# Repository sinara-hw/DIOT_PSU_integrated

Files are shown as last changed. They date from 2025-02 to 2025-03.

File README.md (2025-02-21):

# DIOT_PSU_integrated
DIOT_PSU_integrated  - Power supply module for DIOT system.

## Design Files

Design files (schematics, PCB layouts, BOMs) can be found at [DIOT_PSU_integrated/Releases](https://github.com/sinara-hw/DIOT_PSU_integrated).

## Wiki

More information can be found on the [wiki](https://github.com/sinara-hw/DIOT_PSU_integrated/wiki).

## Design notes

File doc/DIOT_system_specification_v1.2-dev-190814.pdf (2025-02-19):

# Distributed I/O Tier system specification

## v1.2-dev-190813

### Greg Daniluk (BE-CO) <grzegorz.daniluk@cern.ch>

### Evangelia Gousiou, Lalit Patnaik, Christos Gentsos, Ioan Kozsar (BE-CO)

### Mateusz Sosin, Kamil Kucel, Paul Peronnard (EN-SMM)

### Pieter Van Trappen (TE-ABT)

### Alain Antoine, Richard Mompo (TE-MPE)

### Grzegorz Kasprowicz (Creotech Instruments)

## Table of Contents

## Revision table

Date | Version | Comments
2018-12-20 | First draft | First draft released for comments
2019-02-28 | 2 nd draft | Including input from Creotech
2019-03-29 | rd draft 3 | Including monitoring-related backplane connectors
2019-04-11 | 4 th draft | Including input from CERN Eq groups
2019-05-06 | 1.0 release | Ready for crate mechanics & backplane design

## 1 Introduction

Controls and data acquisition systems in accelerators often involve a computing platform (VME, PICMG 1.3, MTCA.4...) connected to Distributed I/O Tier electronics using a fieldbus communication link (Figure 1). The devices in the Distributed I/O Tier communicate directly with various sensors and actuators and are deployed close to the machine. Since these areas are frequently exposed to radiation and because of the very specific needs of CERN systems, these modules not being commercially available, are usually custom in-house developments. Currently, we are missing a centrally supported service at CERN for the custom electronics in this layer.

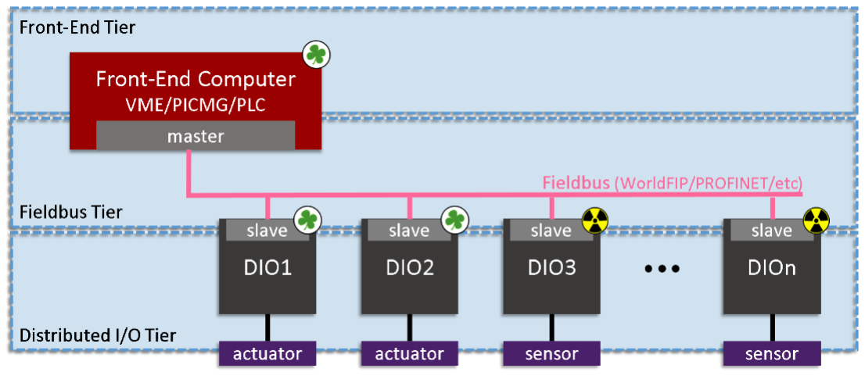
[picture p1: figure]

Figure 1: Three lowest hardware layers of a typical control system

The Distributed I/O Tier project aims at offering a new, modular and reusable hardware kit for various renovations and new systems to be deployed for the High Luminosity LHC (HL-LHC) in 2025. The kit to cover the requirements of the equipment groups in both radiation-exposed and radiation-free areas will consist of the following components (Figure 2):

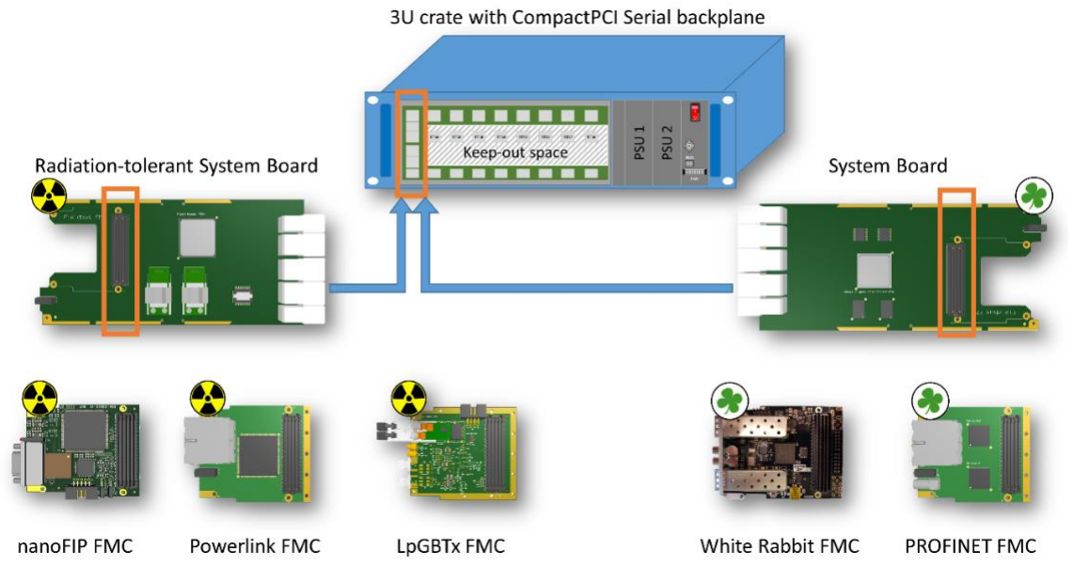
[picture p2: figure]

Figure 2: Distributed I/O Tier modular and reusable hardware kit

- A low-cost CompactPCI Serial chassis with a backplane and redundant power supplies (either off-the-shelf or radiation-tolerant in-house designed).
- Two generic FPGA-based System Boards (radiation-tolerant and non-radiation-tolerant) that interface with the application-specific peripheral boards plugged into the other slots of the 3U crate. Each System Board features a high-performance FPGA for the application-specific logic. A small fraction of the FPGA resources is dedicated to standardised crate diagnostics. The System Boards have an LPC FMC slot, where a fieldbus slave mezzanine is plugged to provide communication with a master and the higher layers of the control system.
- A set of interchangeable, radiation-tolerant and non-radiation-tolerant fieldbus communication mezzanines in the FMC format that implement various communication standards: WorldFIP, Powerlink, LpGBTx, White Rabbit or PROFINET.

This document specifies the Distributed I/O Tier chassis, its components that are common to all equipment groups as well as the customization options to adapt it to specific needs of a particular use case.

## 2 Main 3U crate backplane

There are two options foreseen for the backplane of a Distributed I/O Tier crate. The general recommendation is to use a common CompactPCI Serial backplane (section 2.1). CompactPCI Serial was selected among many industrial modular electronics standards because it features a fully passive backplane and a robust connector targeting transportation applications. Being fully passive, the backplane enables the use of its lines as a set of single-ended or differential lanes for simple communication mechanisms like fast SPI or even direct I/O connections. The DI/OT crate does not make use of the CompactPCI Serial high-speed interconnects (PCIe/SATA/USB) specification, as it would be too complex for the radiation-exposed systems.

By selecting this default and standard approach for DI/OT crate, peripheral boards designed by a specific equipment group can be reused also by other groups. However, in case a particular application cannot benefit from the common CompactPCI Serial backplane (section 2.1), one can also design a custom application-specific backplane preserving some common characteristics with the common backplane (section 9.1).

### 2.1 Common CompactPCI Serial backplane

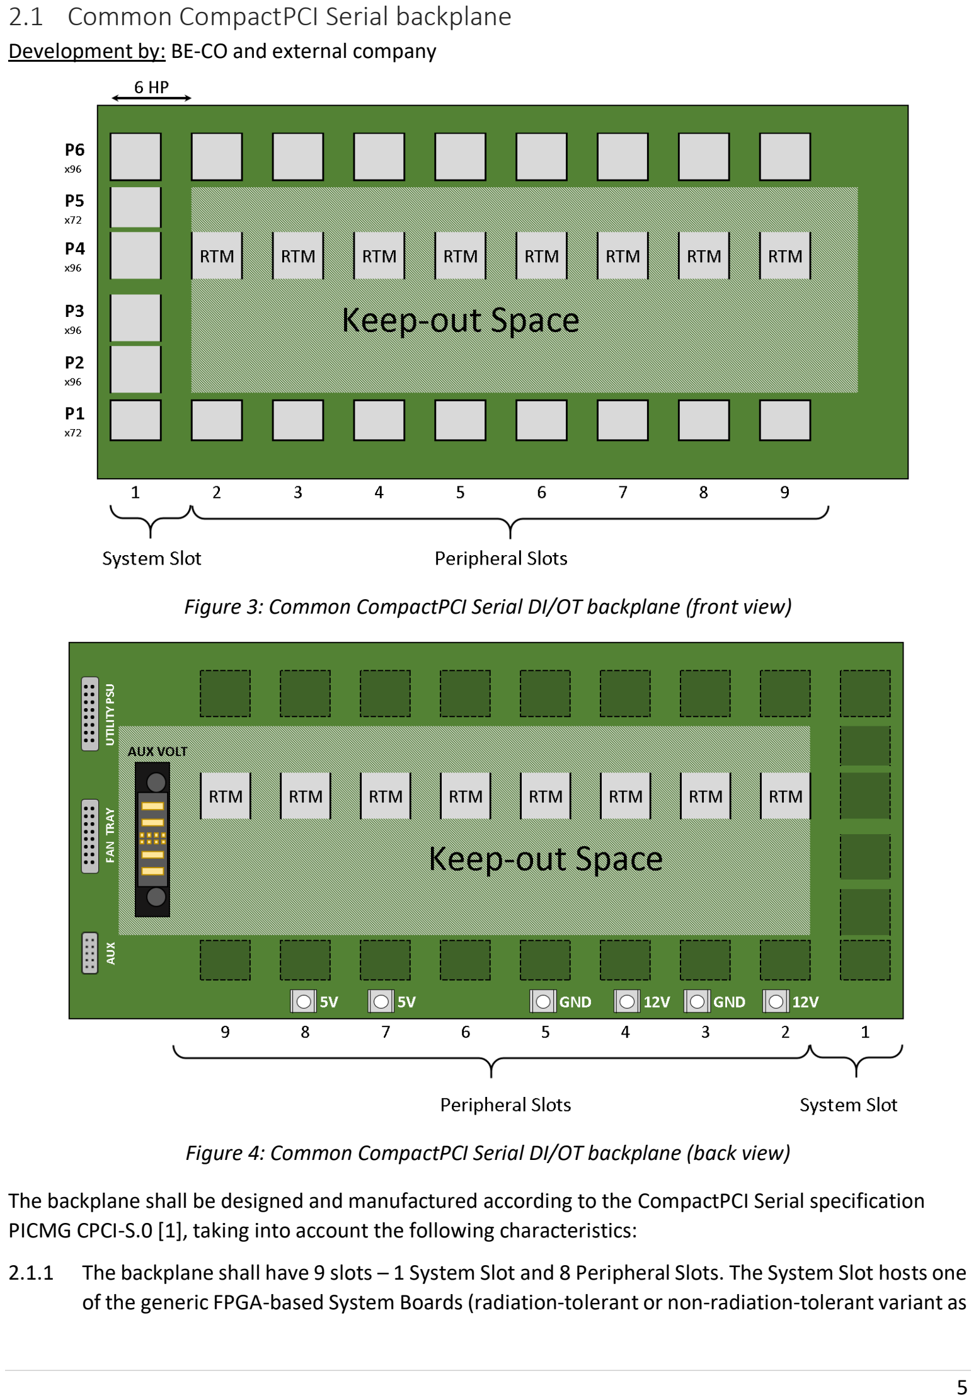
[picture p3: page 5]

Development by: BE-CO and external company

Figure 3: Common CompactPCI Serial DI/OT backplane (front view)

Figure 4: Common CompactPCI Serial DI/OT backplane (back view)

The backplane shall be designed and manufactured according to the CompactPCI Serial specification PICMG CPCI-S.0 [1], taking into account the following characteristics:

2.1.1 The backplane shall have 9 slots – 1 System Slot and 8 Peripheral Slots. The System Slot hosts one of the generic FPGA-based System Boards (radiation-tolerant or non-radiation-tolerant variant as described in section 1) while 8 Peripheral Slots host application-specific boards designed by equipment groups for the needs of their systems.
2.1.2 | The System Slot shall be placed on the left side of the backplane.
2.1.3 | The System Slot shall have a width of 6HP (Horizontal Pitch) i.e. 30.48mm. All Peripheral Slots shall
| have a width of 6HP.
2.1.4 | All Peripheral Slots shall be populated with P1 (72-pin), P4 (96-pin) and P6 (96-pin) Airmax
| connectors. P1 provides power and differential pairs for communication between Peripheral Slots
| and the System Slot. P6 provides additional differential pairs for communication with the System
| Slot. P4 RTM (Rear Transition Module) connector provides additional connectivity with optional
| rear modules and the rest of the Peripheral Boards.
2.1.5 | CPCI-S.0 [1] standard allows two connection topologies of differential pairs available in P6
| connectors of the System Slot and all Peripheral Slots (mesh or single star). The DI/OT backplane
| shall use a single star topology between the System Slot and 8 Peripheral Slots.
2.1.6 | To lower the cost of the backplane, only 16 differential pairs going from the System Slot to the P1
| of 8 Peripheral Slots (2 differential pairs per Peripheral Slot) are foreseen to handle high-speed
| communication (e.g. using MGT FPGA transceivers). Lanes n_PE_Tx00, n_PE_Rx00 (where n is a
| slot number 1..8) in Table 44 and Table 45 of the CPCI-S.0 standard [1] shall be used for this
| purpose and routed accordingly to ensure signal integrity, controlled differential impedance 100Ω
| and length matching with 5mm tolerance.
| Note: The actual use of these lanes depends on the System Board design. E.g. in radiation–
| exposed areas, these high-speed lanes can be used for low-speed communication.
2.1.7 | The 8 differential pairs (one per Peripheral Slot) going from the System Slot to the 8 Peripheral
| Slots (n_PE_CLK+/- in rows 5 and 6 of the System Slot connector P5 according to CPCI-S.0 standard
| [1]) shall provide low-noise distribution of high quality clocks to each of the Peripheral Boards.
| Note: The actual use of these lanes depends on the System Board design. E.g. in radiation–
| exposed areas, these clock distribution lanes can be used for low-speed communication.
2.1.8 | The remaining 120 differential pairs (15 pairs per Peripheral Slot) going from the System Slot to 8
| Peripheral Slots will be used as low-speed communication (e.g. SPI links) or user-defined I/Os.
| Therefore their routing constraints can be relaxed to reduce the cost of the backplane (they will
| not carry Gbps transfer rates from gigabit FPGA transceivers).
2.1.9 | All differential pairs going to a particular Peripheral Slot shall be length matched with 5mm
| tolerance.
2.1.10 Geographical addressing signals (GA0-3) shall be grounded/open for each slot as defined in CPCI-
| S.0 standard [1].
2.1.11 All backplane signals not mentioned in this section (+12V, +5V, GND, general purpose multi-drop
| lines, PSU control signals, reset) shall be routed as specified in the CPCI-S.0 standard [1].
2.1.12 PWRBTN# and PRST# lines defined in CPCI-S.0 standard in the System Slot P1 connector shall be
| routed to AUX IDC connector (Figure 4) in the back of the backplane (full pinout in Table 4).
| Note: These single-ended lines will be connected to the FPGA on the System Board, so their
| functionality can be programmed by the user depending on final application (e.g. to expose UART
| interface in the front panel).
2.1.13 The 11 signals of a System Slot P2 connector that are defined as “general purpose I/O” (in Table
| 44 and Table 45 of PICMG CPCI-S.0 [1]), shall be connected to a set of IDC-type connectors
| (Utility(PSU), FAN TRAY in Figure 4) in the back of the backplane. These lines will be used for wiring

of the components required by crate diagnostics and monitoring (e.g. PMBus for PSU and fan tray monitoring).
2.1.14 The IDC-type connectors (Utility(PSU), FAN TRAY, AUX) shall be equipped with latches to prevent lose contacts, keying to prevent improper insertion (Amphenol 53611-G16-8LF for Utility and FANTRAY; Molex 1719730004 for AUX) and be placed on the left side of the backplane (looking from the back, Figure 4) to allow the use of short ribbon cables to connect to power backplanes and front panel connector.
2.1.15 The pin assignment of the 11 “general purpose I/O” of the System Slot P2 (in Table 44 and Table 45 of CPCI-S.0 [1]) and their wiring to the IDC connectors shall be done according to Table 1.
IO pin | Name | IDC conn | IO pin | Name | IDC conn
P2-07A | M_SCL | Utility(PSU), FANTRAY | P2-07B | M_SDA | Utility(PSU), FANTRAY
P2-08B | P_RST | Utility(PSU) | P2-08C | P_IO0 | Utility(PSU)
P2-07D | P_IO1 | Utility(PSU) | P2-07E | P_IO2 | Utility(PSU)
P2-07G | P_PRES0 | Utility(PSU) | P2-07H | P_PRES1 | Utility(PSU)
P2-07J | F_RST | FANTRAY | P2-07K | F_IO0 | FANTRAY
P2-08J | F_IO1 | FANTRAY | -- | -- | --
Table 1: System Slot "general purpose I/O" assignment

2.1.16 The full pinout of IDC connectors (Utility, FANTRAY, AUX) shall be done according to Table 2, Table 3 and Table 4.
2.1.17 The I²C bus that is shared among all the backplane slots (backplane pins IC_SCL, IC_SDA) shall not be wired to the Utility(PSU) connector as defined by the CPCI-S.0 standard. Instead, the I²C bus exposed through the Utility(PSU) connector (pins M_SCL, M_SDA) is driven directly by the System Board according to Table 1.
2.1.18 The backplane shall have a keep-out area between P1 and P6 connectors of the Peripheral Slots (marked with gray stripes in Figure 3 and Figure 4), where no routing of P1 and P6 signals shall be present – power and ground planes are allowed. If there is such a requirement, one can design a customized backplane by copying the layout of the default backplane (System Slot connections to P1 and P6 of all Peripheral Slots) and populating the “Keep-outspace” with the desired connectors and signaling. The default version of this backplane makes use of the “Keep-out space” to host P4 (marked RTM in Figure 3) and Aux Volt connectors.
Note: the original idea of having a cutout for the whole “Keep-out space”, as described in the initial specification, was dropped as it would compromise the backplane stiffness. Metal supports cannot be fabricated with enough accuracy to prevent deformation and eventually connector damage.
2.1.19 The pin assignment of the Peripheral Slot P4 (RTM) connector shall be compliant with P4 connector in Table 47 and Table 48 of the PICMG CPCI-S.0 [1] standard. The front P4 (RTM) connector (Figure 3) for each slot shall be wired to a mating Airmax connector in the back (Figure 4).
2.1.20 P4 (RTM) I/Os of row 1 (8 signals) are used to distribute two auxiliary voltages provided either by one of the Peripheral Boards, or through the Aux Volt connector (Figure 4). For this reason, two power planes (Vaux1, Vaux2) shall be created in the Keep-out Space of the backplane and connected to P4(RTM) pins according to Table 5.
2.1.21 The Aux Volt connectorshall be the FCI PwrBlade with 4 power contacts and 8 signal contacts (e.g. 51740-10200802AALF). It shall be placed in the “Keep-out space” and its pinout shall be done according to Table 6. In case Peripheral Boards need to be provided with a specific voltage (e.g. to power analog front-end), an auxiliary power supply can be plugged to Aux Volt connector. It inputs +12V DC and produces desired auxiliary voltages (Vaux1 and Vaux2) that are then distributed to all Peripheral Slots over P4(RTM) connectors (Table 5).
2.1.22 The width of Aux Volt rear slot shall be 4HP (Horizontal Pitch).
2.1.23 Corresponding P4 (RTM) I/Os of row 2 (8 signals) shall be connected between all Peripheral Slots. This way an 8-line bus is created that can be used for board-to-board communication (See Table 5).
Note: PCB traces of 8-line bus shall be wide enough to match the current rating of the Airmax connector (0.95A per pin).
2.1.24 The placement, dimensions and tolerance of the mounting holes shall be compliant with section 3.7.1 of the PICMG CPCI-S.0 specification [1].
2.1.25 Power (12V, 5V, GND) shall be provided to the backplane through screw terminals (power bugs) rated for ≥ 50A – see Figure 4 for the proposed power bugs layout.
2.1.26 The signal integrity of the backplane design shall be fully simulated prior the production.
2.1.27 The signal integrity of the backplane shall be measured after the production. Additional, passive System Board and Peripheral Board shall be designed to interface measurement equipment with the backplane.
Pin no. | Signal | Pin no. | Signal
1 | n/c | 2 | GND
3 | GND | 4 | n/c
5 | RTN_Sense | 6 | PS_ON#
7 | +12V_Sense | 8 | PWR_FAIL#
9 | P_PRES0 | 10 | P_PRES1
11 | M_SDA | 12 | M_SCL
13 | P_RST | 14 | P_IO0
15 | P_IO1 | 16 | P_IO2
Table 2: Utility(PSU) connector pinout
Pin no. | Signal | Pin no. | Signal
1 | GND | 2 | GND
3 | F_RST | 4 | +12V
5 | M_SCL | 6 | GND
7 | +5V | 8 | +12V
9 | M_SDA | 10 | GND
11 | F_IO0 | 12 | +12V
13 | F_IO1 | 14 | GND
15 | GND | 16 | +12V
Table 3: FANTRAY connector pinout
Pin no. | Signal | Pin no. | Signal
1 | GND | 2 | +5V
3 | PWRBTN# | 4 | PRST#
Table 4: AUX connector pinout

Pin | A | B | C | D | E | F | G | H | I | J | K | L
4-08 | GND | IO | IO | GND | IO | IO | GND | IO | IO | GND | IO | IO
4-07 | IO | IO | GND | IO | IO | GND | IO | IO | GND | IO | IO | GND
4-06 | GND | IO | IO | GND | IO | IO | GND | IO | IO | GND | IO | IO
4-05 | IO | IO | GND | IO | IO | GND | IO | IO | GND | IO | IO | GND
4-04 | GND | IO | IO | GND | IO | IO | GND | IO | IO | GND | IO | IO
4-03 | IO | IO | GND | IO | IO | GND | IO | IO | GND | IO | IO | GND
4-02 | GND | Bus[0] | Bus[1] | GND | Bus[2] | Bus[3] | GND | Bus[4] | Bus[5] | GND | Bus[6] | Bus[7]
4-01 | Vaux1 | Vaux1 | GND | Vaux1 | Vaux1 | GND | Vaux2 | Vaux2 | GND | Vaux2 | Vaux2 | GND
Table 5: Peripheral Slot P4(RTM) connector pinout
P1 | P2 +12V | D1 Bus[6] | D2 Bus[7] | P3 | P4 GND
| | C1 | C2
| | Bus[4] | Bus[5]
| | B1 | B2
| | Bus[2] | Bus[3]
| | A1 | A2
| | Bus[0] | Bus[1]

Vaux1

Vaux2

Table 6: AUX VOLT connector pinout

## 3 Crate powering

### 3.1 Main power supply

Development by: BE-CO, R2E, TE-EPC (rad-tol variant)
The main power supply receives 230V AC and produces +12V and +5V that are distributed over the main backplane (common CompactPCI Serial or custom application-specific) to the System Board and all Peripheral Boards (Figure 5). Each board produces locally, with low power DC-DC converters and/or LDOs the specific voltages that are needed for its operation.

In radiation-free applications an off-the-shelf 300W main power supply would be used while for radiation-exposed areas a custom rad-tolerant development will be done. Both types of main power supplies shall meet the following characteristics:

3.1.1 | Input voltage: 230V AC, 50Hz
3.1.2 | Outputs: +12V, +5V
3.1.3 | Output power for rad-tolerant variant: 10W (+5V), 100W (+12V)
3.1.4 | Output power for off-the-shelf variant: 10W (+5V), 300W (+12V)
3.1.5 | Ripple and noise: <100mVpp (+12V), <20mVpp (+5V)
3.1.6 | Radiation tolerance (for rad-tolerant variant): ≥ 500Gy
3.1.7 | Switching frequency: 250kHz – 1MHz
3.1.8 | Physical dimensions: 100mm x 160mm x 37mm (8HP)
3.1.9 | Cassette enclosure for high voltage separation and heat dissipation
3.1.10 PMBus monitoring interface (specified in section 8.4). In case of the rad-tolerant PSU, PMBus is
| implemented by the Monitoring Module (specified in section 8.2).
3.1.11 Current sharing line to enable operation in redundancy configuration
3.1.12 Remote On/Off switching

3.1.13 Connector: PwrBlade FCI 51939-667. The pinout compatible with the convention agreed among CompactPCI manufacturers (see Table 7).
3.1.14 The power supply plugs to a power backplane (section 3.2) which is a separate PCB connecting DC voltages and monitoring signals with cables to the main backplane.
P1 | P2 NEUTRAL | P3 PE | P4 DC_IN | P5 DC_RTN | D1 N/A | D2 PWR_FAIL | D3 PRESENT | D4 GND | D5 DEG | D6 +5V | P6 | P7 | P8 | P9 LINE
| | | | | C1 | C2 | C3 | C4 | C5 | C6
| | | | | N/A | N/A | GND | A0 | +5V | +5V
| | | | | B1 | B2 | B3 | B4 | B5 | B6
| | | | | N/A | +12VCS | PS_ON | A1 | SCL | GND
| | | | | A1 | A2 | A3 | A4 | A5 | A6
| | | | | N/A | RTN_Sense | +12V_Sense | A2 | SDA | ENABLE

GND

GND

+12V

+12V

Table 7: PwrBlade FCI 51939-667 power connector pinout

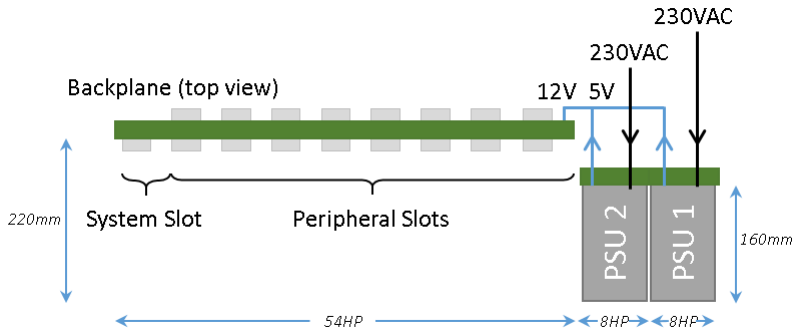
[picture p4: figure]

Figure 5: Main PSU powering scheme

### 3.2 Power backplane

Development by: BE-CO and external company or off-the-shelf product
The role of the power backplane is to interface between the main power supply and the main 3U backplane. The reason of having a power backplane separated from the main backplane is the difference in depth between the System and Peripheral boards (220mm) and the standard CompactPCI Serial power supplies (160mm) – please see section 4 for more details. It is also useful to have it as a separate module for more flexibility on crate mechanical assembly (only one power backplane can be mounted in case redundancy is not needed, power supplies can be placed in the back of the crate if required).

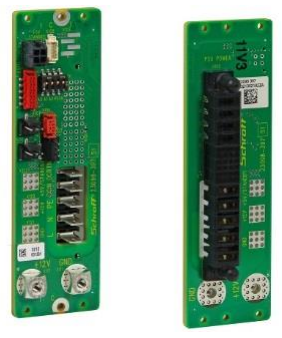
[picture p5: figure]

Figure 6: Off-the-shelf power backplane example (back and front side)

The power backplane shall meet the following characteristics:

3.2.1 | The backplane shall have mechanical dimensions of 100mm x 8HP (40.64m).
3.2.2 | The backplane shall use FCI 51940-473 power connector (receptacle for FCI 51939-667) to
| interface with the main DI/OT power supply (section 3.1)
3.2.3 | The pinout of FCI 51940-473 shall be consistent with the convention agreed among CompactPCI
| manufacturers (see Table 7).
3.2.4 | The 230V AC FASTON terminals of the power connector shall be accessible through a hole in the
| backplane (Figure 6) to ensure no high voltage signals are routed through the backplane.
| Moreover, this way no high voltage contacts are exposed (to avoid electrocution) when the 230V
| FASTON plugs are isolated.
3.2.5 | The backplane shall expose two utility connectors (Utility1, Utility2) with PSU monitoring signals
| (pinout according to Table 8) using IDC connectors with latches to prevent loose contacts. These
| two connectors are used to daisy-chain two power backplanes and the main 3U DI/OT backplane
| (section 2.1). Signals are directly wired between Utility1 and Utility2 with some of them being
| crossed according to Table 8.
3.2.6 | The backplane shall have a jumper that will allow to open/close the CUR_SHARE line between
| Utility1 and Utility2.
3.2.7 | The backplane shall wire the signals of the utility connector to the FCI 51940-473 power connector
| according to Table 8.
3.2.8 | The backplane shall expose +12V, +5V and GND rails using screw terminals (power bugs) rated for
| ≥ 50A.
3.2.9 | The backplane shall be equipped with a DIP switch to configure the addressing lines of the FCI
| power connector (pins C4, B4, A4). Each of these signals shall be connected to GND or floating
| depending on the DIP switch position.

Signal | Utility1 pin | Utility2 pin | FCI pin | Signal | Utility1 pin | Utility2 pin | FCI pin
CUR_SHARE | 1 | 1 | B2 | GND | 2 | 2, 10 | D4
GND | 3 | 3, 16 | D4 | PS_ON# | 6 | 6 | B3
RTN_Sense | 5 | 5 | A3 | PWR_FAIL# | 8 | 8 | D2
+12V_Sense | 7 | 7 | A2 | P_PRES1 | 10 | 9 | --
P_PRES0 | 9 | -- | D3 | M_SCL | 12 | 12 | B5
M_SDA | 11 | 11 | A5 | P_IO0 | 14 | 14 | B1
P_RST | 13 | 13 | A1 | P_IO2 | 16 | 15 | D1
P_IO1 | 15 | -- | C1 | -- | -- | -- | --
Table 8: Power backplane control signals wiring

### 3.3 Aux power supply

Developed by: Equipment groups
In the cases when a specific voltage cannot be produced locally on a Peripheral Board, one can also design and use an auxiliary power supply according to the following characteristics:
3.3.1 | An aux power supply is highly recommended to be a specialized Peripheral Board or an RTM Board
| that receives +12V from the P1 backplane connector and produces the required voltage levels on
| bus lines of the P4 connector (see section 2.1) to be distributed to all Peripheral Boards (Figure
| 7).
| Note: various designs (e.g. QPS electronics, DOROS system) have shown that a very clean voltage
| for analog front-end can be generated using a cascade of DC-DC regulator with one (ripple and
| noise < 5mVpp) or multiple LDOs (ripple and noise ~ 10µVpp). Please see [2] for measurement
| results of 2mVpp ripple on 5V power rail generated by the cascade: Traco AC/DC (TPP-40 105)
| →Murata DC/DC (MEJ2D0515SC) →Texas Instr.LDO (TPS7A49)
3.3.2 | If an aux power supply is placed in the last slot of the main backplane, its maximum width can be
| 10HP. In this case, a 4HP front metal plate next to PSU1 (described in section 4.1) shall be
| removed.
3.3.3 | If 10HP is not sufficient, an aux power supply can be a cassette occupying several peripheral slots,
| e.g. to host a linear power supply with a 50Hz transformer. In such case the Aux PSU cassette
| would directly receive 230V AC, produce the auxiliary voltages with a linear regulator and forward
| the 230V AC to the main PSU (Figure 8).
3.3.4 | The distribution of auxiliary voltages is done over the P4 connector of the common backplane
| (section 2.1) or in a fully custom backplane (section 9.1).
3.3.5 | Aux voltages are distributed only to peripheral boards, the system slot does not receive them.

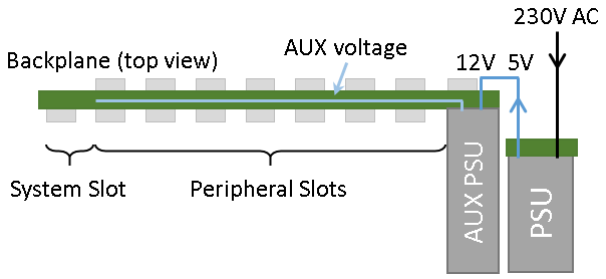
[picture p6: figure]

Figure 7: Powering scheme with Aux PSU (using the common backplane)

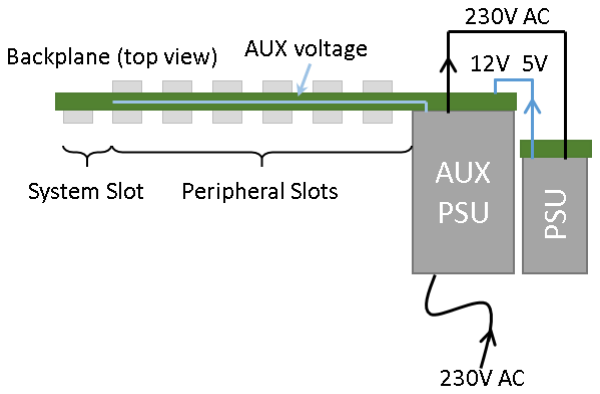
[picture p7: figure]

Figure 8: Powering scheme with aux linear PSU (using a custom backplane)

## 4 3U Chassis mechanics and cabling

Developed by: BE-CO with equipment groups and external company

To cover the requirements of various systems the chassis is modular and consists of:

- 3U CompactPCI Serial crate assembled from standard 3U sub-rack components (available from various crate manufacturers and through CERN stores). It hosts the main backplane (described in 2.1), two power backplanes (described in 3.2), and a front panel (described in 4.2).
- Optional 1U fan tray, which can be mounted below or on top of the main chassis (described in section 5).

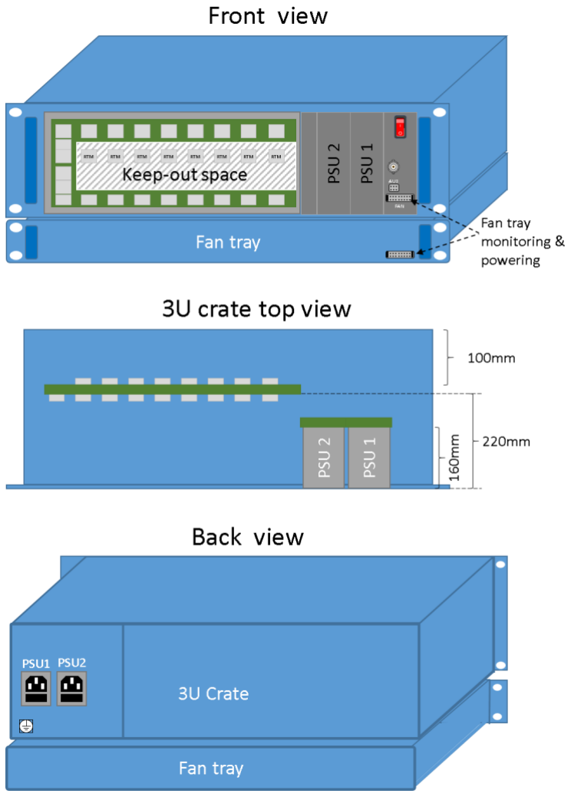
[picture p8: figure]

Figure 9: DIOT crate and fan tray mockup

### 4.1 Main 3U crate

The main 3U crate shall be compliant with the following characteristics:

4.1.1 | Height shall be 3U (3 rack units)
4.1.2 | Width shall be 19” with 84 HP (horizontal pitch) usable space.
4.1.3 | The crate shall be assembled from standard 3U sub-rack components compatible with the
| mechanical standards IEC 60297-3 and IEEE 1101.10-1996 [3].
4.1.4 | The crate shall be equipped with rack mounting holes and front handles.
4.1.5 | The crate shall be equipped with a front and rear attachment plane compliant with section 8 of
| the IEEE 1101.10-1996 standard [3], to enable locking each front and rear board using an IEEE
| Injector/Ejector Handle.
4.1.6 | The crate shall be equipped with 2 power backplanes (as defined in section 3.2) to host two main
| power supplies (section 3.1) in a load sharing redundancy configuration – a current sharing
| signaling cable shall be connected between the two power backplanes (Figure 11).

4.1.7 Both power supply slots shall be placed on the right side of the main backplane (PSU1, PSU2 in Figure 9).
4.1.8 | The crate shall mount and connect the front panel as defined in section 4.2.
4.1.9 | The crate shall mount a 4HP front metal cover to fill free space between the PSU1 and the last
| backplane slot. This front metal cover shall be equipped with EMC gasket.
4.1.10 The rear metal cover of the crate shall be split in two segments: 26 HP (Horizontal Pitch) metal
| panel hosting two 230V AC IEC power entry sockets and the earth screw; 58 HP (Horizontal Pitch)
| metal panel covering the rest of the rear space. In case there is a need to plug rear modules, the
| 58 HP metal panel will be removed.
4.1.11 The crate shall have perforated bottom and top covers (Ø4mm) to allow better airflow.
4.1.12 The crate and fan tray enclosure shall be compliant with IP2X rating.
4.1.13 The crate shall host the common CompactPCI Serial backplane (section 2.1) – power and signaling
| cabling, and backplane mounting holes shall be placed accordingly.
4.1.14 The crate shall host front boards (System Board and Peripheral Boards) which are 220mm long.
| Therefore the backplane needs to be mounted 60mm deeper than in regular CPCIs crates.
4.1.15 Each slot of the crate shall have a width of 6HP. Card guide rails shall be mounted accordingly. 4.1.16 220mm card guide rails according to IEEE 1101.10 shall be used. For the System Slot (slot 1) a red
| guide rail shall be used (e.g. Schroff P/N 64560-091), while for all Peripheral Slots (slot 2-9) gray
| guide rails shall be used (e.g. Schroff P/N 64560-092).
4.1.17 The crate shall leave 100mm of rear space behind the backplane for optional rear transition
| modules or an expansion backplane. The mechanics of the crate shall provide metal supports for
| the 100mm card guide rails for optional rear modules. However, these rails shall not be mounted.
4.1.18 The crate shall provide mechanical mounting and cabling of the monitoring components specified
| in section 8.
4.1.19 The Utility(PSU) connector of the main backplane shall be connected using a ribbon cable with
| the Utility connectors of both power backplanes (Figure 11).
4.1.20 Two 230V AC IEC power entry sockets with a fuse and EMC filter shall be placed in the back of the
| crate (Figure 9) and wired with FASTON terminals to the front panel (Figure 11). These power
| entry modules shall be compatible with a locking mechanism to prevent accidental removal (e.g.
| V-Lock from Schurter, IEC-LOCK from Schaffner).
4.1.21 The earth screw shall be placed in the back of the crate and connected to earth contacts of 230V
| AC IEC power sockets as depicted in Figure 11.
4.1.22 The cabling of the crate shall be done according to wiring diagram in Figure 11.
4.1.23 All outer covers of the crate (top, bottom, left, right, front, back) shall be powder coated with
| color RAL XXXX (TBD influence on EMC).

### 4.2 Front panel

Figure 10: Front panel mockup

The front panel module (Figure 10) shall be compliant with the following characteristics:

4.2.1 The front panel shall be installed on the right side of the crate, next to the power supplies (Figure
9) and have a width of 10HP.
4.2.2 | The front panel shall be equipped with an EMC gasket.
4.2.3 | The front panel shall host an on/off power switch, BNC connector for external power cycling, a
| fan tray connector and an AUX connector.
4.2.4 | The fan tray connector shall be a 16-pin IDC with latches preventing accidental removal
| (Amphenol 53611-G16-8LF). It shall be connected through a ribbon cable to the fan connector in
| the main backplane (pinout specified in Table 3).
4.2.5 | The Front AUX connector shall be a 6-pin IDC. It shall be connected to the signals arriving from
| the 4-pin Back AUX connector (wired to the AUX connector on the main backplane) and 12V
| arriving from the fan tray connector according to Table 9.
4.2.6 | The BNC connector can optionally input an external signal (5V TTL, active high) that is used for
| power cycling the crate. It shall drive a relay connected in series with the power button to break
| on request the 230V AC power going to the power supplies.
4.2.7 | The aforementioned components shall be placed on a PCB screwed to the metal plate of the
| front panel to ensure proper and reliable mounting.
Signal | Front Aux pin | Back Aux pin | Signal | Front Aux pin | Back Aux pin
GND | 1 | 1 | PRST# | 4 | 4
+5V | 2 | 2 | GND | 5 | 1
PWRBTN# | 3 | 3 | +12V | 6 | --
Table 9: Front panel Aux connectors pin assignment

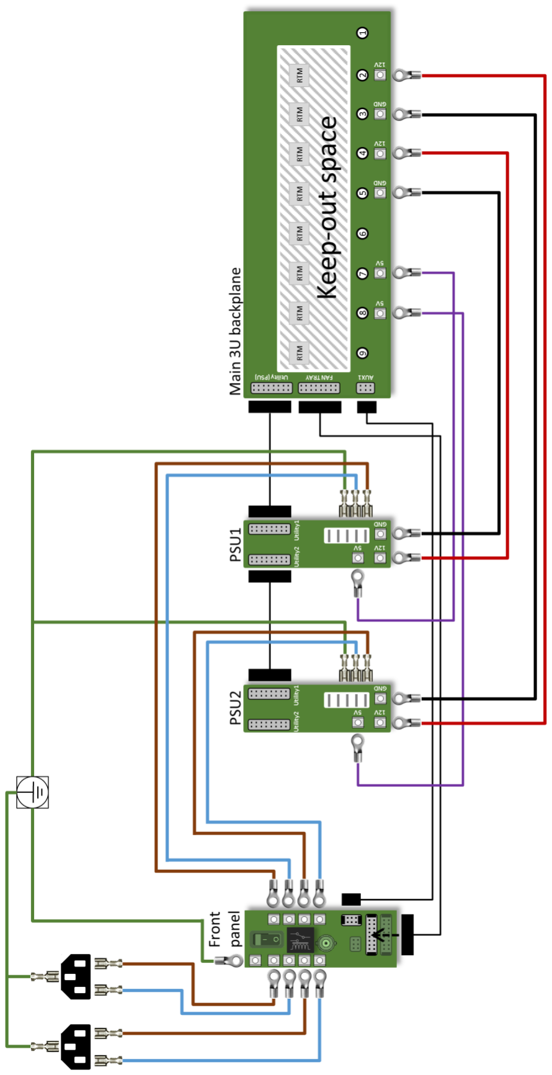
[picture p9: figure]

Figure 11: DI/OT crate wiring diagram (back view of the front panel and backplanes)

## 5 Fan tray

Developed by: BE-CO with equipment groups or off-the-shelf fan tray

The fan tray is an additional module to the main 3U CompactPCI Serial crate. It could be placed in the rack, below or above the 3U crate for systems that require better heat dissipation (e.g. deployed in radiation-free areas). Either an off-the-shelf 12VDC powered or a custom made fan tray can be used. The custom made fan tray shall contain BLDC (Brushless DC) fans, temperature sensors and a monitoring module (the same one used for power supply monitoring) and should meet the following requirements:

5.1.1 | The fan tray’s height shall be 1U (1 rack unit)
5.1.2 | The fan tray’s width shall be 19”.
5.1.3 | The fan tray shall be equipped with rack mounting holes and front handles
5.1.4 | The placement of fans inside the fan tray shall be such to provide air flow for all the front cards
| and the power supplies.
5.1.5 | The fan tray shall receive power and control signals through a 16-pin IDC connector (with latches
| to prevent accidental removal) from the main 3U chassis. The fans inside the fan tray shall be
| powered from +12V and the monitoring module from +5V. There is no additional power supply
| mounted inside the fan tray.
5.1.6 | The fan tray shall draw not more than 36W from the +12V power provided by the IDC connector.
| Note: This estimation is a safe upper limit based on the current that can be provided over the IDC
| connector (1A per-pin, current pinout of the connector in Table 3 dedicates 4 pins to provide +12V
| power). It can be reached in radiation-free areas where powerful, off the shelf PSU is used (e.g.
| 300W). In radiation-exposed areas the fan tray is expected to draw not more than 10-15W.
5.1.7 | The fan tray shall host a monitoring module (the same one as used for power supply monitoring,
| see section 8.2 for details) that communicates with the System Board of the 3U crate over a
| PMBus interface.
5.1.8 | The pinout of the front connector of the fan tray shall be identical to that of the IDC connector
| exposed on the front panel of the main 3U crate (see Table 3).
5.1.9 | The fan tray shall feature a fully passive board hosting a front IDC connector, fan connectors and
| pin headers to plug the monitoring module.
5.1.10 The fan tray shall ensure air flow at the level of 360 CFM (Cubic Feet per Minute) (three fans
| each providing 120 CFM) - TBD further simulations are ongoing.
| Note: This is based on DI/OT proof of concept off-the-shelf crate. Thermal simulations to be
| done, to determine what’s the sufficient minimum air flow, especially that in radiation-exposed
| areas the main power supply can provide 100W total power (comparing to 300W outside
| radiation).

## 6 System Board

Developed by: BE-CO with equipment groups

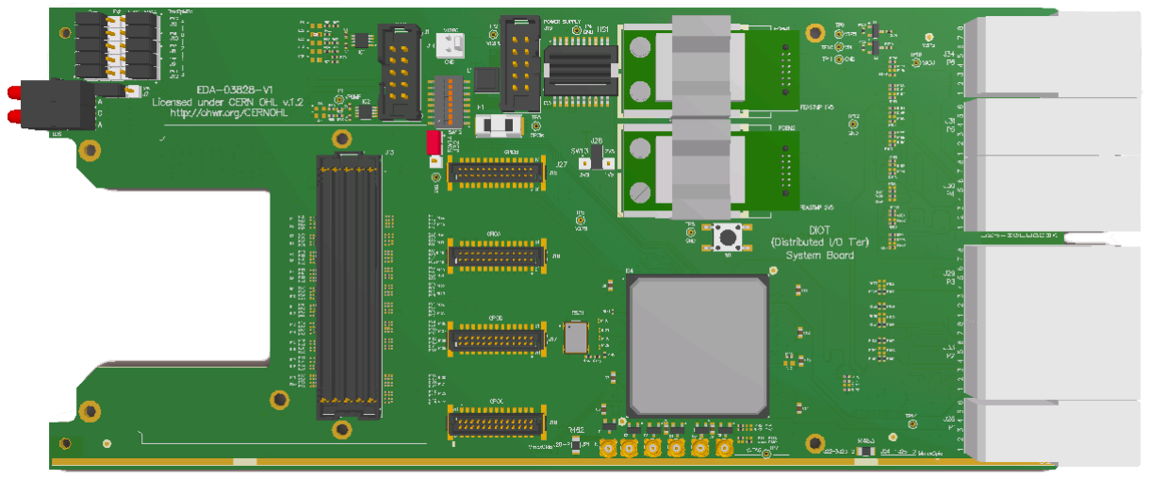
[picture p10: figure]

Figure 12: DI/OT System Board example

The common Distributed I/O Tier System Board (Figure 12) is the main FPGA-based board in the DI/OT crate. It is the main crate controller that communicates with application-specific peripheral boards, fieldbus mezzanine and is responsible for crate monitoring. The project foresees a design of two variants of the system board (radiation-tolerant and non-radiation-tolerant) of the following characteristics:

6.1.1 | The board’s dimensions are 100mm x 220mm x ≤ 6HP
6.1.2 | The board shall be equipped with an LPC FMC connector to host a communication mezzanine.
6.1.3 | In addition to point 6.1.2, the non-radiation-tolerant variant of the system board shall connect 3
| of the HPC gigabit transceiver interfaces to the FPGA to support in total 4 high speed transceivers
| of a communication mezzanine.
6.1.4 | The board may host any other (not only communication) LPC FMC mezzanine if required by the
| application.
6.1.5 | The FPGA selection for radiation-tolerant variant shall be made between a Flash-based FPGA (e.g.
| SmartFusion2) and a radiation-hard SRAM-based NanoXplore FPGA (NG-Medium).
6.1.6 | The non-radiation-tolerant variant shall feature a System-on-Chip (e.g. Xilinx Zynq/Zynq
| Ultrascale). A more powerful unit is required outside radiation since for those applications
| equipment groups will be implementing more complex data processing.
| Note: If a DI/OT installation spans across both radiation-exposed and radiation-free areas, one
| can also use the radiation-tolerant variant of the System Board in radiation-free areas to keep the
| whole system homogeneous.
6.1.7 | The board shall have a set of 6 Airmax connectors (P1 – P6) to communicate with the DIOT
| backplane, following the CompactPCI Serial specification PICMG CPCI-S.0 [1] (see table below).

Designator | Rows | Pins | Walls | P/N
P1 | 6 | 72 | 4 | 10052825-101LF
P2, P3, P4 | 8 | 96 | 2 | 10052837-101LF
P5 | 6 | 72 | 2 | 10052824-101LF
P6 | 8 | 96 | 4 | 10052838-101LF
6.1.8 | The pinout of the P1 – P6 Airmax connectors shall be compatible with the CompactPCI Serial
| specification PICMG CPCI-S.0 [1], with the difference that all the PCIe, USB, SATA, Ethernet lanes
| are used as general purpose differential lanes for simple communication with peripheral boards
| (e.g. using fast SPI or direct I/O connections).
6.1.9 | The system board shall produce locally, using DC-DC converters and LDOs, voltage levels required
| for the FPGA, FMC mezzanine and all other on-board components.
6.1.10 The FPGA of the System Board shall connect to the 11 general purpose I/O lines (“IO” signals in Table 44 and Table 45 of PICMG CPCI-S.0 [1]) to use them for various monitoring-related
| interfaces (e.g. PSUs PMBus, Fan tray monitoring) according to Table 1.

## 7 Peripheral Boards

Developed by: Equipment groups

Peripheral boards are the application-specific boards, to be installed in slots 2-9 of the 3U crate. They are designed by the equipment groups to fit a specific application and share some common characteristics to be re-usable between groups:

7.1.1 | The board’s dimensions are 100mm x 220mm x ≤ 6HP
| Note: Peripheral Board can be wider than 6HP, but in that case it will block adjacent backplane
| peripheral slots.
7.1.2 | The board shall use a 72-pin P1 Airmax connector (see table in 6.1.7) to communicate with the
| System Board over the common CompactPCI Serial backplane. The P1 connector provides:
| • Power: +12V, +5V, GND
| • 14 LVDS differential pairs between the Peripheral Slot and the System Slot of which:
| • 2 pairs are routed for high-speed communication (e.g. MGT FPGA transceivers)
| • 1 pair is routed to provide a high quality clock signal dedicated to this slot
| • 11 pairs can be used for any sort of communication up to tens-Mbps (e.g. fast SPI
| or direct I/O connections).
| • A reset line common to all Peripheral Slots.
| • A service I2C bus, shared between all the slots. It is planned to be used for Peripheral
| Boards identification.
| • 5 multi-drop single-ended lines shared between all the slots. Those can be used as internal
| interlock lines.
7.1.3 | Optionally, a P6 Airmax connector can be used if more communication lanes between the
| Peripheral Slot and the System Slot are needed. The P6 connector provides:
| • 4 LVDS differential pairs between the Peripheral Slot and the System Slot that can be used
| for any sort of communication up to tens-Mbps (e.g. fast SPI or direct I/O connections).

7.1.4 | Optionally, a 96-pin P4 Airmax connector (RTM) can be used if direct communication between
| Peripheral Slots is required or if a Peripheral Slot needs an RTM (Rear Transition Module). The P4
| connector provides:
| • 16 single-ended lines shared between all the slots. Each line can carry up to 0.95A. Those
| can be used for inter-board communication or for distribution of auxiliary voltages
| between the Peripheral Slots.
| • 48 pins are routed to the back of the backplane for RTM communication.
7.1.5 | If the functionality of the P4, P6 connectors is not needed, the connectors may not be placed on
| the Peripheral Board.
7.1.6 | The board receives through the P1 connector +12V (main power rail) and +5V (low power standby
| rail) and should produce locally, using DC-DC or LDO, the voltages required to its operation. The
| total power provided by the power supplies for the 12V is 100W (for radiation-tolerant in-house
| designed PSU) and for the +5V is 10W; this includes the consumption of the System Board and of
| the Fan Tray (if needed).
7.1.7 | Auxiliary voltages (e.g. for analog frontend) can be provided through the P4 (RTM) connector (see
| section 2.1).
7.1.8 | The pinout of the P1 (and optionally P6) Airmax connectors shall be compatible with the
| CompactPCI Serial specification PICMG CPCI-S.0 [1] , with the difference that all the PCIe, USB,
| SATA, Ethernet lanes are used as general purpose differential lanes for simple communication
| with peripheral boards (e.g. using fast SPI or direct I/O connections).
7.1.9 | If additional shielding is needed (e.g. for an analog front-end), a peripheral board can be housed
| in a 3U cassette.
7.1.10 If a custom application-specific backplane is used, the selection of the connector for peripheral
| boards is up to the designer (e.g. DIN-type connectors can be used if needed).

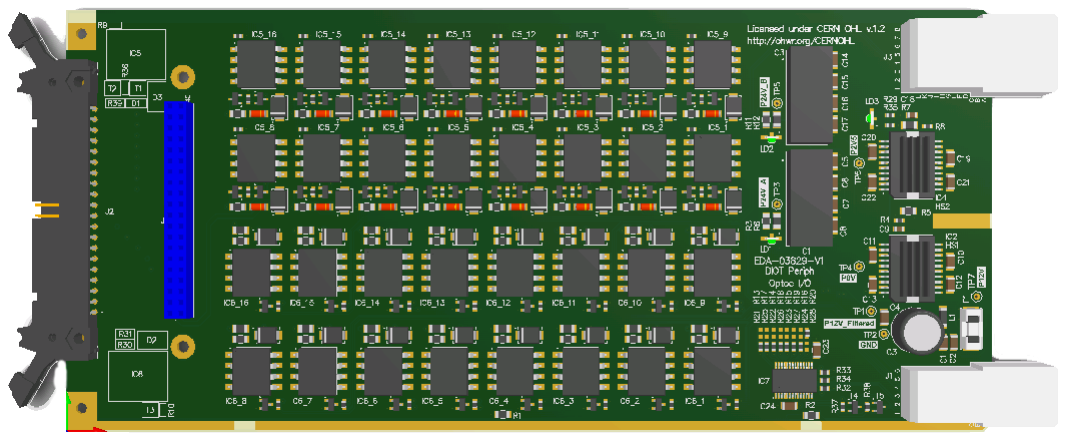
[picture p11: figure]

Figure 13: DI/OT Peripheral Board example

## 8 Crate monitoring

Developed by: BE-CO with Equipment groups

Monitoring of the DIOT crate is implemented in the main FPGA of the System Board and utilizes 11 general purpose I/O backplane lines to communicate with the power supplies and the optional fan tray. Following the PICMG CPCI-S.0 specification [1], the communication with these modules is based on the I²C interface. According to the standard an I

2C System Management Bus is shared between the power supplies, fan tray, and all the peripheral boards. In the DIOT crate two separate I

2C busses are distinguished:

- I

2C System Management Bus – exposed on the utility connector (as defined in the CPCI-S.0 standard), but connected to the System Slot using 2 of the general purpose I/O backplane lines (see M_SCL, M_SDA lines in Table 1). It is used to read monitoring quantities of the power supplies and the fan tray.
- I

2C Peripheral Bus – shared bus between the System Slot and all Peripheral Slots (utilizes IC_SCL, IC_SDA backplane lines). It is used to read the board ID of each Peripheral Board for autodetection.

### 8.1 Monitored Quantities

In this section the measurements that comprise the readout part of the diagnostics are described.

8.1.1 | For each main PSU, voltage and current monitoring for each of the power rails (12V / 5V) shall be
| provided, along with one temperature (might be worth it to put more, one ambient and two major
| loads, TBD) readout.
8.1.2 | Multiple temperature sensors shall be supported by means of the monitoring modules in the
| PSU(s) and the optional fan tray. These may be mounted on the top or bottom grill, the backplane
| or in otherwise strategic locations, depending on the application.
8.1.3 | Depending on the fan test results (TBD) the user may be able to monitor the speed of the fans in
| the optional fan tray and control the fan set-points.

### 8.2 Monitoring module

Developed by: BE-CO

A monitoring module shall be developed to provide PMBus (I²C–based) monitoring and control for the PSU(s) and the fan tray. It shall be a small form-factor module (Figure 14) that can be mounted on a motherboard.

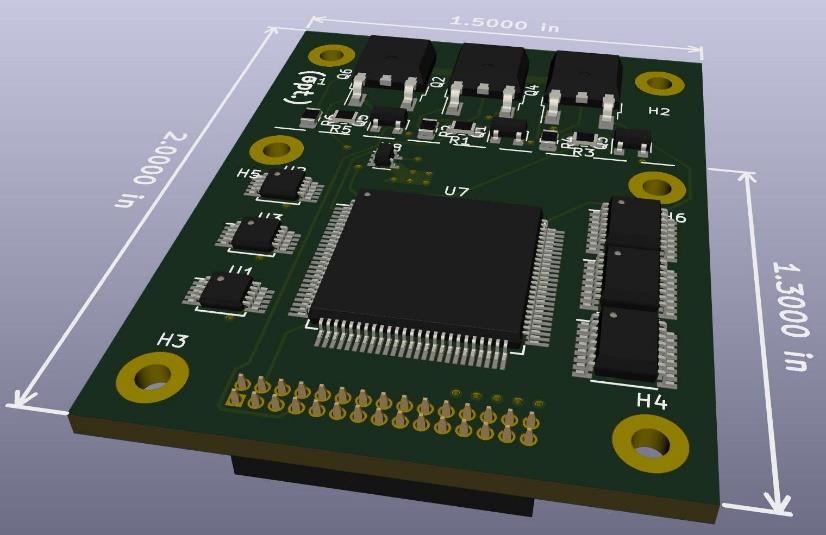
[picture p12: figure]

Figure 14: Mockup of the monitoring module

8.2.1 | When driving fans, the module shall be powered by 12V and 5V power rails. When it is not
| driving any fans, supplying the 5V power rail will be enough (e.g. inside the PSU).
8.2.2 | A reset signal from the FPGA on the System Board shall be provided to the microcontroller in
| case a watchdog fails in radiation-exposed areas and it enters a fault condition (e.g. line P_RST in
Table 2).
8.2.3 | A subset of the PMBus protocol (specified in section 8.4) shall be used to interface with the
| monitoring module. Two pins shall be used to set the module’s I 2C address.
8.2.4 | Voltage and current monitoring of up to three power rails shall be supported.
8.2.5 | Up to three temperature sensors of PT100/PT1000 type (or I 2C, TBD) shall be supported.
8.2.6 | PWM control of up to three 12V fans shall be provided. Up to 1A of current shall be provided to
| each fan.
8.2.7 | If the fans provide a dedicated PWM control pin, the power FET part of the module becomes
| redundant. Thus, a reduced-size version of the module may also be produced (notice the dashed
| line in Figure 14) or jumpers can be added to reroute the 12V so that the same board might be
| physically cut, TBD.
8.2.8 | If the fans provide speed sense pins, speed measurements shall be also made available through
| the PMBus interface.
8.2.9 | An SWD (Serial Wire Debug) programming interface shall be provided through the main
| connector and through an on-board header connector.
8.2.10 Exact details of this module have to remain TBD for now (most probably it will feature
| ATSAMD21G18 microcontroller, radiation tests are ongoing).

### 8.3 Monitoring software services

8.3.1 | CCS
8.3.2 | COSMOS
8.3.3 | Remote reprogramming framework

### 8.4 PMBus for DI/OT

## 9 Customization examples

This section lists examples how the common and modular DI/OT hardware kit can be customized for various applications.

### 9.1 Custom application-specific backplane

Development by: Equipment groups

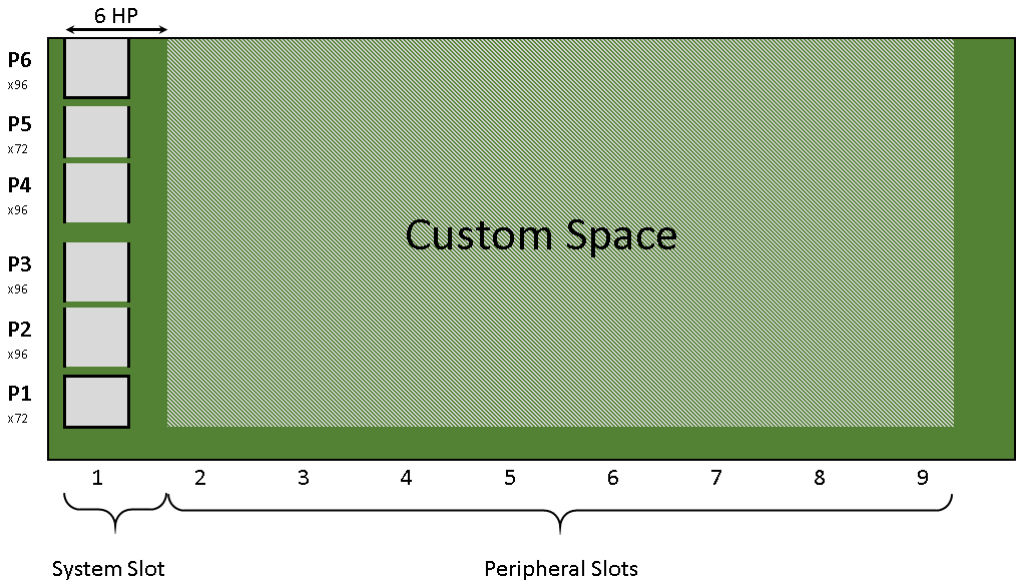
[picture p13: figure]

Figure 15: Custom DIOT backplane

A fully custom backplane may be designed for applications with constrains that cannot be fulfilled by the common DI/OT backplane. Such a custom backplane shall have the following characteristics for compatibility with the DI/OT crate mechanics:

9.1.1 | The backplane shall have a System Slot made of P1 – P6 Airmax connectors and 6HP width, as
| specified in section 2.1 and the Compact PCI Serial PICMG CPCI-S.0 [1] standard.
9.1.2 | The backplane shall have a set of IDC connectors (Utility(PSU), FANTRAY, AUX) as defined in
| section 2.1.
9.1.3 | The backplane shall distribute +12V and +5V power from the main power supply to the System
| Slot and IDC connectors (Utility(PSU), FANTRAY).
9.1.4 | The backplane shall have mounting holes compatible with a common DI/OT backplane (section
| 2.1).
9.1.5 | The backplane shall not be more than 54 HP wide (including the System Slot) in case it has to fit
| in the crate mechanics as defined in section 4.1.
9.1.6 | The rest of the backplane (“Custom space”) can host any application-specific connectors and
| additional signal wiring. It can for example be used to distribute any non-standard auxiliary
| voltages to Peripheral Boards (e.g. for analog front-ends) or to host I/O BNC connectors for
| external sensors/actuators.

### 9.2 BLM controller

For the renovation of the LHC BLM system, the following customization of the DI/OT system could be proposed:

9.2.1 Custom BLM backplane designed according to section 9.1. This custom backplane will host a common System Board, a BLECF2 connector for a BLM acquisition card, 8 BNC connectors for BLM high voltage signals, and a BLEIPU connector for an auxiliary BLM power supply (Figure 16).

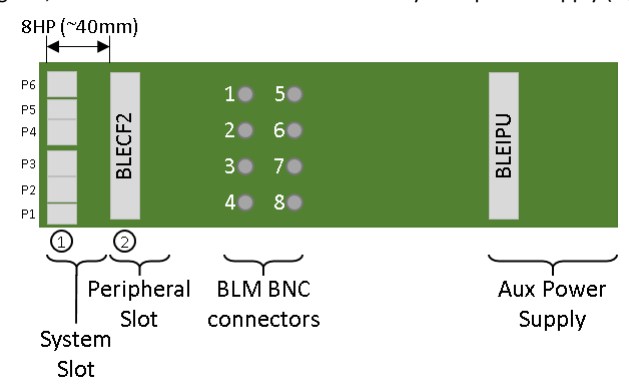
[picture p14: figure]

Figure 16: Custom BLM backplane proposal

9.2.2 | BLEIPU used as an Aux Power Supply according to section 3.3 – it receives 230V AC, produces with
| a transformer and a linear regulator a clean voltage for a BLM analog front-end, and provides
| 230V AC to the main power supply (section 3.1). The auxiliary “clean” voltage produced by the
| BLEIPU is distributed to the BLECF2 connector in the custom BLM backplane.
9.2.3 | As an alternative to 9.2.2, BLEIPU can be a Peripheral Board generating the required voltages for
| the BLM analog front-end taking as inputs the +12VDC generated by the main PSU described in
| section 3.1. The measurements documented in report [2] prove that BLM requirements for ripple
| and noise < 10mVpp on a 5V power rail can be satisfied with a cascade of a DC-DC regulator and
| an LDO.
9.2.4 | An optional fan tray defined in section 5 is installed on top of the main 3U chassis. This fan tray is
| powered and monitored from the main 3U chassis through a front panel connector (Figure 17).
9.2.5 | The common System Board (section 6) implements crate and PSU monitoring and any additional
| slow control needed. It uses a WorldFIP network (already deployed at the BLM locations in the
| tunnel) to communicate with higher layers of the control system. Optionally, the System Board
| can also implement an independent remote reprogramming channel for in-field, remote
| reconfiguration of an FPGA placed on the BLECF2 board.
9.2.6 | The DI/OT 3U crate together with the fan tray can be placed in any standard 19” cabinet with any
| external 19” mechanical components that are required by the BLM system (air deflector, cables
| holder, etc.).

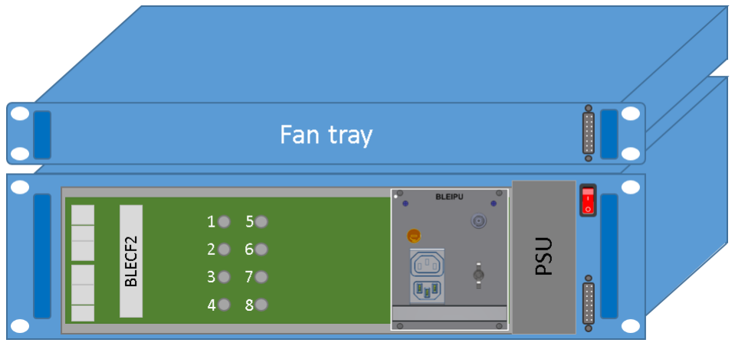
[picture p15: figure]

Figure 17: Customized BLM DI/OT setup proposal

## 10 References

[1] PICMG CompactPCI Serial (CPCI–S.0 ) Rev 2.0 https://www.picmg.org/openstandards/compactpci-serial/
(inside CERN only) https://wikis.cern.ch/download/attachments/103445302/PICMG%20CPCI-S.0.pdf
[2] Measurements of power supply ripple and noise for uQDS crate https://wikis.cern.ch/download/attachments/103445337/UQDS_PSU_Ripple.pdf
[3] IEEE 1101.10-1996 standard
https://ieeexplore.ieee.org/document/588320

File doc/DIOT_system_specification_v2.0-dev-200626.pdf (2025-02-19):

# Distributed I/O Tier system specification

## v2.0-dev-200626

### Greg Daniluk (BE-CO) <grzegorz.daniluk@cern.ch>

### Evangelia Gousiou, Lalit Patnaik, Christos Gentsos, Ioan Kozsar (BE-CO)

### Mateusz Sosin, Kamil Kucel, Paul Peronnard (EN-SMM)

### Pieter Van Trappen (TE-ABT)

### Alain Antoine, Richard Mompo (TE-MPE)

### Grzegorz Kasprowicz (Creotech Instruments)

## Table of Contents

## Revision table

Date | Version | Comments
2018-12-20 | First draft | First draft released for comments
2019-02-28 | 2 nd draft | Including input from Creotech
2019-03-29 | 3 rd draft | Including monitoring-related backplane connectors
2019-04-11 | 4 th draft | Including input from CERN Eq groups
2019-05-06 | 1.0 release | Ready for crate mechanics & backplane design
2020-07-XX | 2.0 release | Completed crate design

## 1 Introduction

Controls and data acquisition systems in accelerators often involve a computing platform (VME, PICMG 1.3, MTCA.4...) connected to Distributed I/O Tier electronics using a fieldbus communication link (Figure 1). The devices in the Distributed I/O Tier communicate directly with various sensors and actuators and are deployed close to the machine. Since these areas are frequently exposed to radiation and because of the very specific needs of CERN systems, these modules not being commercially available, are usually custom in-house developments. Currently, we are missing a centrally supported service at CERN for the custom electronics in this layer.


Figure 1: Three lowest hardware layers of a typical control system

The Distributed I/O Tier project aims at offering a new, modular and reusable hardware kit for various renovations and new systems to be deployed for the High Luminosity LHC (HL-LHC) in 2025. The kit to cover the requirements of the equipment groups in both radiation-exposed and radiation-free areas will consist of the following components (Figure 2):

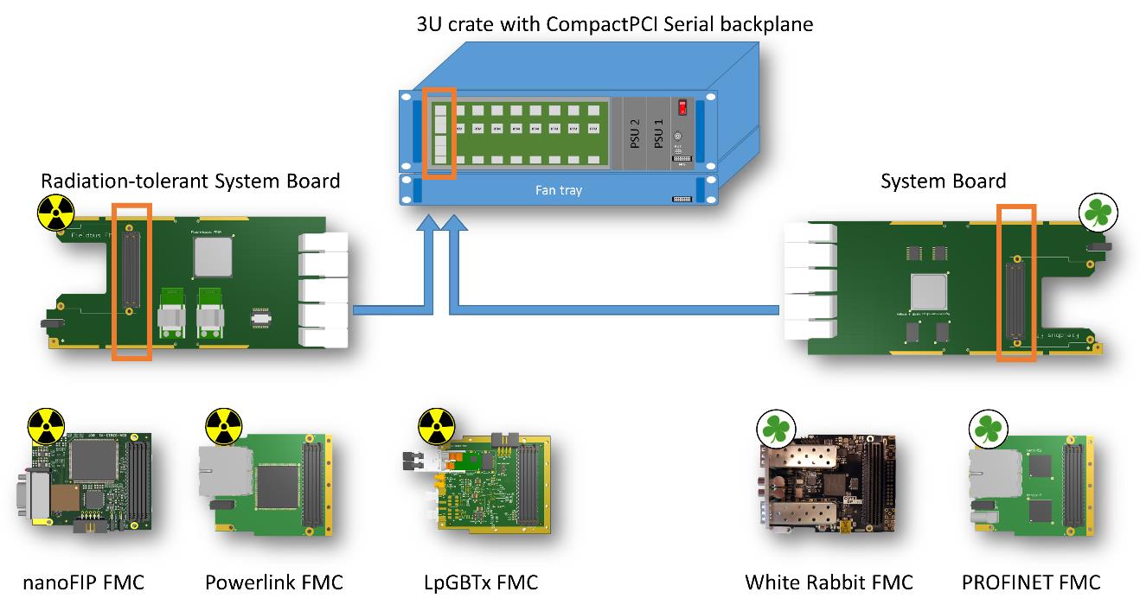
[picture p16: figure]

Figure 2: Distributed I/O Tier modular and reusable hardware kit

- A low-cost CompactPCI Serial chassis with a backplane, redundant power supplies (either off-the-shelf or radiation-tolerant in-house designed) and an optional fan tray.
- Two generic FPGA-based System Boards (radiation-tolerant and non-radiation-tolerant) that interface with the application-specific peripheral boards plugged into the other slots of the 3U crate. Each System Board features a high-performance FPGA for the application-specific logic. A small fraction of the FPGA resources is dedicated to standardised crate diagnostics. The System Boards have an LPC FMC slot, where a fieldbus slave mezzanine is plugged to provide communication with a master and the higher layers of the control system.
- A set of interchangeable, radiation-tolerant and non-radiation-tolerant fieldbus communication mezzanines in the FMC format that implement various communication standards: WorldFIP, Powerlink, LpGBTx, White Rabbit or PROFINET.

This document specifies the Distributed I/O Tier chassis, its components that are common to all equipment groups as well as the customization options to adapt it to specific needs of a particular use case.

## 2 Main 3U crate backplane

There are two options foreseen for the backplane of a Distributed I/O Tier crate. The general recommendation is to use a common CompactPCI Serial backplane (section 2.1). CompactPCI Serial was selected among many industrial modular electronics standards because it features a fully passive backplane and a robust connector targeting transportation applications. Being fully passive, and providing a set of connections in star topology (Figure 3) the backplane enables the use of its lines as a set of single-ended or differential lanes for simple communication mechanisms like fast SPI or even direct I/O connections. The DI/OT crate does not make use of the CompactPCI Serial high-speed interconnects (PCIe/SATA/USB) specification, as it would be too complex for the radiation-exposed systems.

By selecting this default and standard approach for DI/OT crate, peripheral boards designed by a specific equipment group can be reused also by other groups. However, in case a particular application cannot benefit from the common CompactPCI Serial backplane (section 2.1), one can also design a custom application-specific backplane preserving some common characteristics with the common backplane (section 9.1).

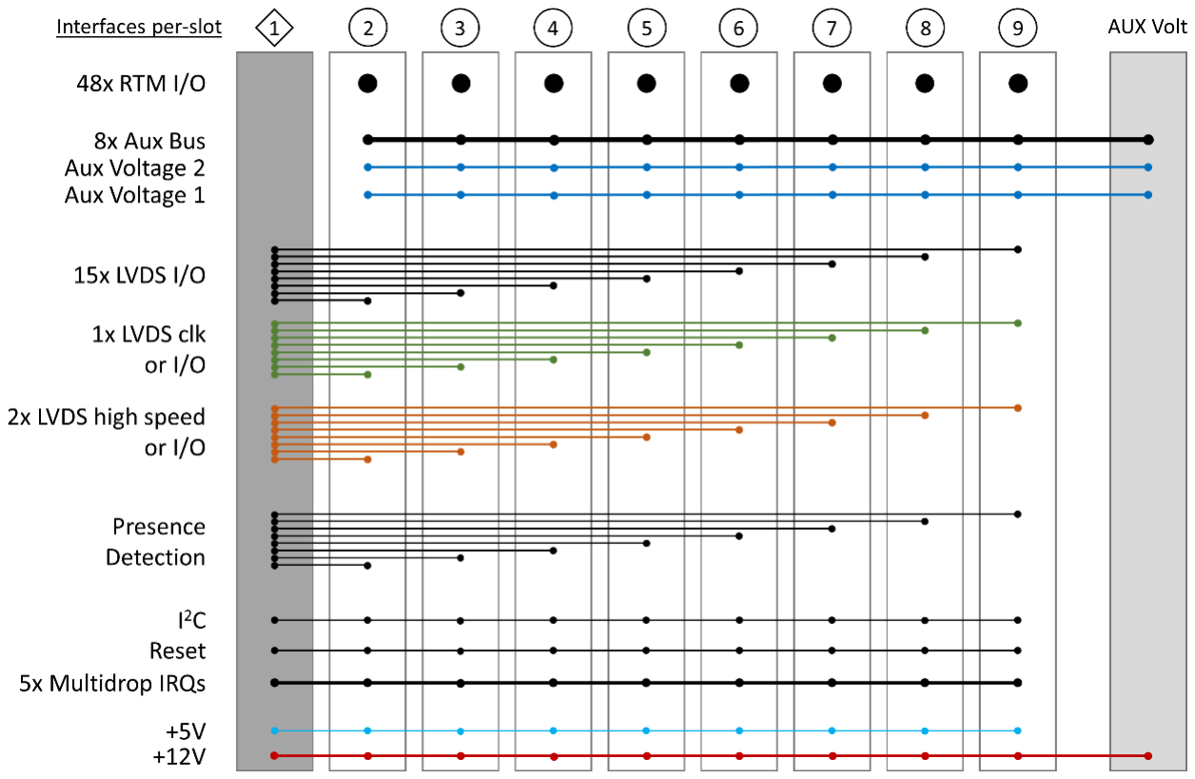
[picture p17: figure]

Figure 3: Common backplane connections topology (1 - System Slot; 2-9 - Peripheral Slots)

### 2.1 Common CompactPCI Serial backplane

Development by: BE-CO and external company

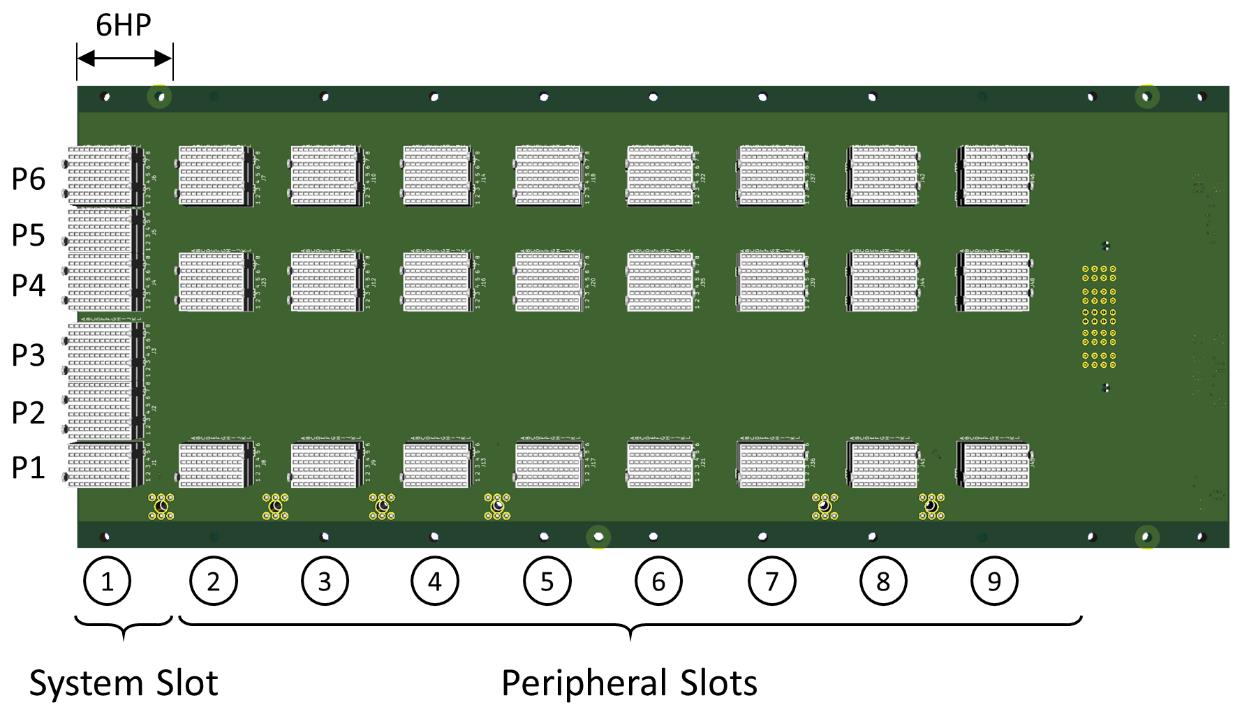
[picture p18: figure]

Figure 4: Common CompactPCI Serial DI/OT backplane (front view)

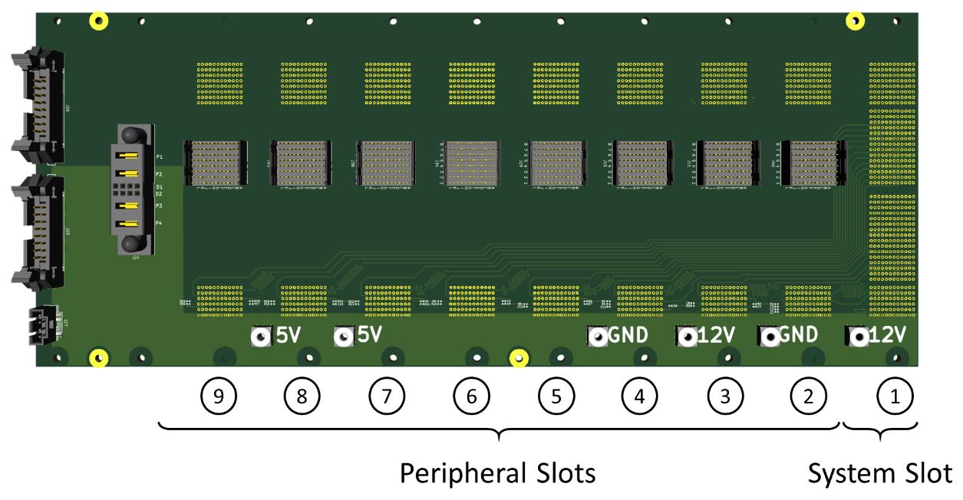
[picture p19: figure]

Figure 5: Common CompactPCI Serial DI/OT backplane (back view)

The backplane shall be designed and manufactured according to the CompactPCI Serial specification PICMG CPCI-S.0 [1], taking into account the following characteristics:

2.1.1 The backplane shall have 9 slots – 1 System Slot and 8 Peripheral Slots. The System Slot hosts one of the generic FPGA-based System Boards (radiation-tolerant or non-radiation-tolerant variant as described in section 1) while 8 Peripheral Slots host application-specific boards designed by equipment groups for the needs of their systems.

2.1.2 | The System Slot shall be placed on the left side of the backplane.
2.1.3 | The System Slot shall have a width of 6HP (Horizontal Pitch) i.e. 30.48mm. All Peripheral Slots shall
| have a width of 6HP.
2.1.4 | All Peripheral Slots shall be populated with P1 (72-pin), P4 (96-pin) and P6 (96-pin) Airmax
| connectors. P1 provides power and differential pairs for communication between Peripheral Slots
| and the System Slot. P6 provides additional differential pairs for communication with the System
| Slot. P4 RTM (Rear Transition Module) connector provides additional connectivity with optional
| rear modules and the rest of the Peripheral Boards.
| Note: Tx and Rx lanes for CPCI-S PCIe, USB3.0, SATA, Ethernet interfaces are crossed in the
| backplane.
2.1.5 | CPCI-S.0 [1] standard allows two connection topologies of differential pairs available in P6
| connectors of the System Slot and all Peripheral Slots (mesh or single star). The DI/OT backplane
| shall use a single star topology between the System Slot and 8 Peripheral Slots.
2.1.6 | To lower the cost of the backplane, only 16 differential pairs going from the System Slot to the P1
| of 8 Peripheral Slots (2 differential pairs per Peripheral Slot) are foreseen to handle high-speed
| communication (e.g. using MGT FPGA transceivers). Lanes n_PE_Tx00, n_PE_Rx00 (where n is a
| slot number 1..8) in Table 44 and Table 45 of the CPCI-S.0 standard [1] shall be used for this
| purpose and routed accordingly to ensure signal integrity, controlled differential impedance 100Ω
| and length matching with 5mm tolerance.
| Note: The actual use of these lanes depends on the System Board design. E.g. in radiation–
| exposed areas, these high-speed lanes can be used for low-speed communication.
2.1.7 | The 8 differential pairs (one per Peripheral Slot) going from the System Slot to the 8 Peripheral
| Slots (n_PE_CLK+/- in rows 5 and 6 of the System Slot connector P5 according to CPCI-S.0 standard
| [1]) shall provide low-noise distribution of high quality clocks to each of the Peripheral Boards.
| Note: The actual use of these lanes depends on the System Board design. E.g. in radiation–
| exposed areas, these clock distribution lanes can be used for low-speed communication.
2.1.8 | The remaining 120 differential pairs (15 pairs per Peripheral Slot) going from the System Slot to 8
| Peripheral Slots will be used as low-speed communication (e.g. SPI links) or user-defined I/Os.
| Therefore their routing constraints can be relaxed to reduce the cost of the backplane (they will
| not carry Gbps transfer rates from gigabit FPGA transceivers and they will not be length-matched).
2.1.9 | All differential pairs going to a particular Peripheral Slot shall be length matched with 5mm
| tolerance.
2.1.10 Geographical addressing signals (GA0-3) shall be grounded/open for each slot as defined in CPCI-
| S.0 standard [1].
2.1.11 All backplane signals not mentioned in this section (+12V, +5V, GND, general purpose multi-drop
| lines, PSU control signals, reset) shall be routed as specified in the CPCI-S.0 standard [1].
2.1.12 PWRBTN# and PRST# lines defined in CPCI-S.0 standard in the System Slot P1 connector shall be
| routed to AUX IDC connector (Figure 5) in the back of the backplane (full pinout in Table 4).
| Note: These single-ended lines will be connected to the FPGA on the System Board, so their
| functionality can be programmed by the user depending on final application (e.g. to expose UART
| interface in the front panel).
2.1.13 The 11 signals of a System Slot P2 connector that are defined as “general purpose I/O” (in Table
| 44 and Table 45 of PICMG CPCI-S.0 [1]), shall be connected to a set of IDC-type connectors
| (Utility(PSU), FAN TRAY in Figure 5) in the back of the backplane. These lines will be used for wiring

of the components required by crate diagnostics and monitoring (e.g. PMBus for PSU and fan tray monitoring).
2.1.14 The IDC-type connectors (Utility(PSU), FAN TRAY, AUX) shall be equipped with latches to prevent lose contacts, keying to prevent improper insertion (Amphenol 53611-G16-8LF for Utility and FANTRAY; Molex 1719730004 for AUX) and be placed on the left side of the backplane (looking from the back, Figure 5) to allow the use of short ribbon cables to connect to power backplanes and front panel connector.
2.1.15 The pin assignment of the 11 “general purpose I/O” of the System Slot P2 (in Table 44 and Table 45 of CPCI-S.0 [1]) and their wiring to the IDC connectors shall be done according to Table 1.
IO pin | Name | IDC conn | IO pin | Name | IDC conn
P2-07A | M_SCL | Utility(PSU), FANTRAY | P2-07B | M_SDA | Utility(PSU), FANTRAY
P2-08B | P_RST | Utility(PSU) | P2-08C | P_IO0 | Utility(PSU)
P2-07D | P_IO1 | Utility(PSU) | P2-07E | P_IO2 | Utility(PSU)
P2-07G | P_PRES0 | Utility(PSU) | P2-07H | P_PRES1 | Utility(PSU)
P2-07J | F_RST | FANTRAY | P2-07K | F_IO0 | FANTRAY
P2-08J | F_IO1 | FANTRAY | -- | -- | --
Table 1: System Slot "general purpose I/O" assignment

2.1.16 The full pinout of IDC connectors (Utility, FANTRAY, AUX) shall be done according to Table 2, Table 3 and Table 4.
2.1.17 The I²C bus that is shared among all the backplane slots (backplane pins IC_SCL, IC_SDA) shall not be wired to the Utility(PSU) connector as defined by the CPCI-S.0 standard. Instead, the I²C bus exposed through the Utility(PSU) connector (pins M_SCL, M_SDA) is driven directly by the System Board according to Table 1.
2.1.18 The pin assignment of the Peripheral Slot P4 (RTM) connector shall be compliant with P4 connector in Table 47 and Table 48 of the PICMG CPCI-S.0 [1] standard. The front P4 (RTM) connector (Figure 4) for each slot shall be wired to a mating Airmax connector in the back (Figure 5).
2.1.19 P4 (RTM) I/Os of row 1 (8 signals) are used to distribute two auxiliary voltages provided either by one of the Peripheral Boards, or through the Aux Volt connector (Figure 5). For this reason, two power planes (Vaux1, Vaux2) shall be created in the P4(RTM) space of the backplane and connected to P4(RTM) pins according to Table 5.
2.1.20 The Aux Volt connectorshall be the FCI PwrBlade with 4 power contacts and 8 signal contacts (e.g. 51740-10200802AALF). It shall be placed on the back side of the backplane and its pinout shall be done according to Table 6. In case Peripheral Boards need to be provided with a specific voltage (e.g. to power analog front-end), an auxiliary power supply can be plugged to Aux Volt connector. It inputs +12V DC and produces desired auxiliary voltages (Vaux1 and Vaux2) that are then distributed to all Peripheral Slots over P4(RTM) connectors (Table 5).
2.1.21 The width of Aux Volt rear slot shall be 4HP (Horizontal Pitch).
2.1.22 Corresponding P4 (RTM) I/Os of row 2 (8 signals) shall be connected between all Peripheral Slots. This way an 8-line bus is created that can be used for board-to-board communication (See Table 5).
Note: PCB traces of 8-line bus shall be wide enough to match the current rating of the Airmax connector (0.95A per pin).

2.1.23 The placement, dimensions and tolerance of the mounting holes shall be compliant with section 3.7.1 of the PICMG CPCI-S.0 specification [1].
2.1.24 Power (12V, 5V, GND) shall be provided to the backplane through screw terminals (power bugs) rated for ≥ 50A – see Figure 5 for the proposed power bugs layout.
2.1.25 The signal integrity of the backplane design shall be fully simulated prior the production.
2.1.26 The signal integrity of the backplane shall be measured after the production. Additional, passive System Board and Peripheral Board shall be designed to interface measurement equipment with the backplane.
Pin no. | Signal | Pin no. | Signal
1 | n/c | 2 | GND
3 | GND | 4 | n/c
5 | RTN_Sense | 6 | PS_ON#
7 | +12V_Sense | 8 | PWR_FAIL#
9 | P_PRES0 | 10 | P_PRES1
11 | M_SDA | 12 | M_SCL
13 | P_RST | 14 | P_IO0
15 | P_IO1 | 16 | P_IO2
Table 2: Utility(PSU) connector pinout
Pin no. | Signal | Pin no. | Signal
1 | GND | 2 | GND
3 | F_RST | 4 | +12V
5 | M_SCL | 6 | GND
7 | +5V | 8 | +12V
9 | M_SDA | 10 | GND
11 | F_IO0 | 12 | +12V
13 | F_IO1 | 14 | GND
15 | GND | 16 | +12V
Table 3: FANTRAY connector pinout
Pin no. | Signal | Pin no. | Signal
1 | GND | 2 | +5V
3 | PWRBTN# | 4 | PRST#
Table 4: AUX connector pinout
Pin | A | B | C | D | E | F | G | H | I | J | K | L
4-08 | GND | IO | IO | GND | IO | IO | GND | IO | IO | GND | IO | IO
4-07 | IO | IO | GND | IO | IO | GND | IO | IO | GND | IO | IO | GND
4-06 | GND | IO | IO | GND | IO | IO | GND | IO | IO | GND | IO | IO
4-05 | IO | IO | GND | IO | IO | GND | IO | IO | GND | IO | IO | GND
4-04 | GND | IO | IO | GND | IO | IO | GND | IO | IO | GND | IO | IO
4-03 | IO | IO | GND | IO | IO | GND | IO | IO | GND | IO | IO | GND
4-02 | GND | Bus[0] | Bus[1] | GND | Bus[2] | Bus[3] | GND | Bus[4] | Bus[5] | GND | Bus[6] | Bus[7]
4-01 | Vaux1 | Vaux1 | GND | Vaux1 | Vaux1 | GND | Vaux2 | Vaux2 | GND | Vaux2 | Vaux2 | GND
Table 5: Peripheral Slot P4(RTM) connector pinout

P1 | P2 +12V | D1 Bus[6] | D2 Bus[7] | P3 | P4 GND
| | C1 | C2
| | Bus[4] | Bus[5]
| | B1 | B2
| | Bus[2] | Bus[3]
| | A1 | A2
| | Bus[0] | Bus[1]

Vaux1

Vaux2

Table 6: AUX VOLT connector pinout

## 3 Crate powering

### 3.1 Main power supply

Development by: BE-CO, R2E, TE-EPC (rad-tol variant)
The main power supply receives 230V AC and produces +12V and +5V that are distributed over the main backplane (common CompactPCI Serial or custom application-specific) to the System Board and all Peripheral Boards (Figure 6). Each board produces locally, with low power DC-DC converters and/or LDOs the specific voltages that are needed for its operation.

In radiation-free applications an off-the-shelf 300W main power supply would be used while for radiation-exposed areas a custom rad-tolerant development will be done. Both types of main power supplies shall meet the following characteristics:

3.1.1 | Input voltage: 230V AC, 50Hz
3.1.2 | Outputs: +12V, +5V
3.1.3 | Output power for rad-tolerant variant: 10W (+5V), 100W (+12V)
3.1.4 | Output power for off-the-shelf variant: 10W (+5V), 300W (+12V)
3.1.5 | Ripple and noise: <100mVpp (+12V), <20mVpp (+5V)
3.1.6 | Radiation tolerance (for rad-tolerant variant): ≥ 500Gy
3.1.7 | Switching frequency: 250kHz – 1MHz
3.1.8 | Physical dimensions: 100mm x 160mm x 37mm (8HP)
3.1.9 | Cassette enclosure for high voltage separation and heat dissipation
3.1.10 PMBus monitoring interface (specified in section 8.4). In case of the rad-tolerant PSU, PMBus is
| implemented by the Monitoring Module (specified in section 8.2).
3.1.11 Current sharing line to enable operation in redundancy configuration
3.1.12 Remote On/Off switching
3.1.13 Connector: PwrBlade FCI 51939-667. The pinout compatible with the convention agreed among
| CompactPCI manufacturers (see Table 7).
3.1.14 The power supply plugs to a power backplane (section 3.2) which is a separate PCB connecting DC
| voltages and monitoring signals with cables to the main backplane.

P1 | P2 NEUTRAL | P3 PE | P4 DC_IN | P5 DC_RTN | N/A | PWR_FAIL | PRESENT | GND | DEG | +5V | P6 | P7 | P8
| | | | | D1 C1 | D2 C2 | D3 C3 | D4 C4 | D5 C5 | D6 C6 | P9 LINE
| | | | | N/A | N/A | GND | A0 | +5V | +5V
| | | | | B1 | B2 | B3 | B4 | B5 | B6
| | | | | N/A | +12VCS | PS_ON | A1 | SCL | GND
| | | | | A1 | A2 | A3 | A4 | A5 | A6
| | | | | N/A | RTN_Sense | +12V_Sense | A2 | SDA | ENABLE

GND

GND

+12V

+12V

Table 7: PwrBlade FCI 51939-667 power connector pinout


Figure 6: Main PSU powering scheme

### 3.2 Power backplane

Development by: BE-CO and external company or off-the-shelf product
The role of the power backplane is to interface between the main power supply and the main 3U backplane. The reason of having a power backplane separated from the main backplane is the difference in depth between the System and Peripheral boards (220mm) and the standard CompactPCI Serial power supplies (160mm) – please see section 4 for more details. It is also useful to have it as a separate module for more flexibility on crate mechanical assembly (only one power backplane can be mounted in case redundancy is not needed, power supplies can be placed in the back of the crate if required).


Figure 7: Off-the-shelf power backplane example (back and front side)

The power backplane shall meet the following characteristics:

3.2.1 | The backplane shall have mechanical dimensions of 100mm x 8HP (40.64m).
3.2.2 | The backplane shall use FCI 51940-473 power connector (receptacle for FCI 51939-667) to
| interface with the main DI/OT power supply (section 3.1)
3.2.3 | The pinout of FCI 51940-473 shall be consistent with the convention agreed among CompactPCI
| manufacturers (see Table 7).
3.2.4 | The 230V AC FASTON terminals of the power connector shall be accessible through a hole in the
| backplane (Figure 7) to ensure no high voltage signals are routed through the backplane.
| Moreover, this way no high voltage contacts are exposed (to avoid electrocution) when the 230V
| FASTON plugs are isolated.
3.2.5 | The backplane shall expose two utility connectors (Utility1, Utility2) with PSU monitoring signals
| (pinout according to Table 8) using IDC connectors with latches to prevent loose contacts. These
| two connectors are used to daisy-chain two power backplanes and the main 3U DI/OT backplane
| (section 2.1). Signals are directly wired between Utility1 and Utility2 with some of them being
| crossed according to Table 8.
3.2.6 | The backplane shall have a jumper that will allow to open/close the CUR_SHARE line between
| Utility1 and Utility2.
3.2.7 | The backplane shall wire the signals of the utility connector to the FCI 51940-473 power connector
| according to Table 8.
3.2.8 | The backplane shall expose +12V, +5V and GND rails using screw terminals (power bugs) rated for
| ≥ 50A.
3.2.9 | The backplane shall be equipped with a DIP switch to configure the addressing lines of the FCI
| power connector (pins C4, B4, A4). Each of these signals shall be connected to GND or floating
| depending on the DIP switch position.

Signal | Utility1 pin | Utility2 pin | FCI pin | Signal | Utility1 pin | Utility2 pin | FCI pin
CUR_SHARE | 1 | 1 | B2 | GND | 2 | 2, 10 | D4
GND | 3 | 3, 16 | D4 | PS_ON# | 6 | 6 | B3
RTN_Sense | 5 | 5 | A2 | PWR_FAIL# | 8 | 8 | D2
+12V_Sense | 7 | 7 | A3 | P_PRES1 | 10 | 9 | --
P_PRES0 | 9 | -- | D3 | M_SCL | 12 | 12 | B5
M_SDA | 11 | 11 | A5 | P_IO0 | 14 | 14 | B1
P_RST | 13 | 13 | A1 | P_IO2 | 16 | 15 | D1
P_IO1 | 15 | -- | C1 | -- | -- | -- | --
Table 8: Power backplane control signals wiring

### 3.3 Aux power supply

Developed by: Equipment groups
In the cases when a specific voltage cannot be produced locally on a Peripheral Board, one can also design and use an auxiliary power supply according to the following characteristics:
3.3.1 | An aux power supply is highly recommended to be a specialized Peripheral Board or an RTM Board
| that receives +12V from the P1 backplane connector and produces the required voltage levels on
| bus lines of the P4 connector (see section 2.1) to be distributed to all Peripheral Boards (Figure
| 8).
| Note: various designs (e.g. QPS electronics, DOROS system) have shown that a very clean voltage
| for analog front-end can be generated using a cascade of DC-DC regulator with one (ripple and
| noise < 5mVpp) or multiple LDOs (ripple and noise ~ 10µVpp). Please see [2] for measurement
| results of 2mVpp ripple on 5V power rail generated by the cascade: Traco AC/DC (TPP-40 105)
| →Murata DC/DC (MEJ2D0515SC) →Texas Instr.LDO (TPS7A49)
3.3.2 | If an aux power supply is placed in the last slot of the main backplane, its maximum width can be
| 10HP. In this case, a 4HP front metal plate next to PSU1 (described in section 4.1) shall be
| removed.
3.3.3 | If 10HP is not sufficient, an aux power supply can be a cassette occupying several peripheral slots,
| e.g. to host a linear power supply with a 50Hz transformer. In such case the Aux PSU cassette
| would directly receive 230V AC, produce the auxiliary voltages with a linear regulator and forward
| the 230V AC to the main PSU (Figure 9).
3.3.4 | The distribution of auxiliary voltages is done over the P4 connector of the common backplane
| (section 2.1) or in a fully custom backplane (section 9.1).
3.3.5 | Aux voltages are distributed only to peripheral boards, the system slot does not receive them.


Figure 8: Powering scheme with Aux PSU (using the common backplane)


Figure 9: Powering scheme with aux linear PSU (using a custom backplane)

## 4 3U Chassis mechanics and cabling

Developed by: BE-CO with equipment groups and external company

To cover the requirements of various systems the chassis is modular and consists of:

- 3U CompactPCI Serial crate assembled from standard 3U sub-rack components (available from various crate manufacturers and through CERN stores). It hosts the main backplane (described in 2.1), two power backplanes (described in 3.2), and a front panel (described in 4.2).
- Optional 1U fan tray, which can be mounted below or on top of the main chassis (described in section 5).

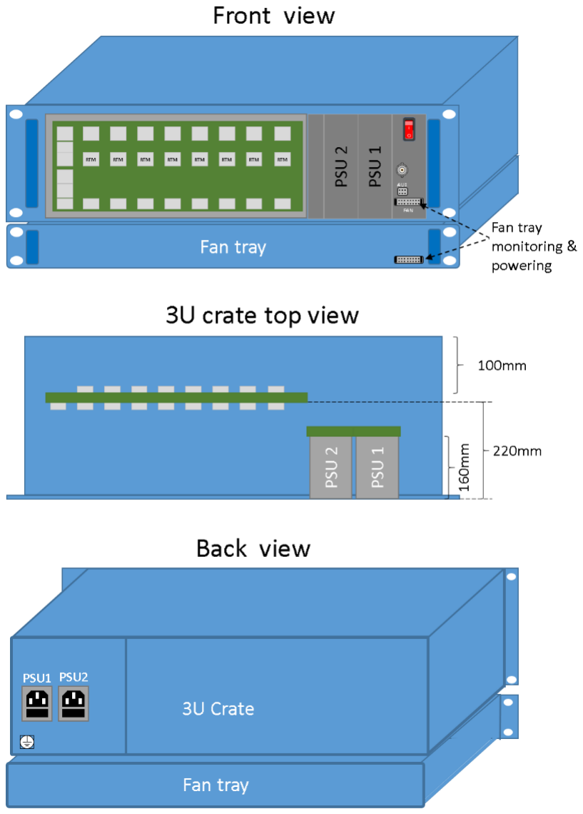
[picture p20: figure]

Figure 10: DIOT crate and fan tray mockup

### 4.1 Main 3U crate

The main 3U crate shall be compliant with the following characteristics:

4.1.1 | Height shall be 3U (3 rack units)
4.1.2 | Width shall be 19” with 84 HP (horizontal pitch) usable space.
4.1.3 | The crate shall be assembled from standard 3U sub-rack components compatible with the
| mechanical standards IEC 60297-3 and IEEE 1101.10-1996 [3].
4.1.4 | The crate shall be equipped with rack mounting holes and front handles.
4.1.5 | The crate shall be equipped with a front and rear attachment plane compliant with section 8 of
| the IEEE 1101.10-1996 standard [3], to enable locking each front and rear board using an IEEE
| Injector/Ejector Handle.
4.1.6 | The crate shall be equipped with 2 power backplanes (as defined in section 3.2) to host two main
| power supplies (section 3.1) in a load sharing redundancy configuration – a current sharing
| signaling cable shall be connected between the two power backplanes (Figure 12).

4.1.7 Both power supply slots shall be placed on the right side of the main backplane (PSU1, PSU2 in Figure 10).
4.1.8 | The crate shall mount and connect the front panel as defined in section 4.2.
4.1.9 | The crate shall mount a 4HP front metal cover to fill free space between the PSU1 and the last
| backplane slot. This front metal cover shall be equipped with EMC gasket.
4.1.10 The rear metal cover of the crate shall be split in two segments: 26 HP (Horizontal Pitch) metal
| panel hosting two 230V AC IEC power entry sockets and the earth screw; 58 HP (Horizontal Pitch)
| metal panel covering the rest of the rear space. In case there is a need to plug rear modules, the
| 58 HP metal panel will be removed.
4.1.11 The crate shall have perforated bottom and top covers (Ø4mm) to allow better airflow.
4.1.12 The crate and fan tray enclosure shall be compliant with IP2X rating.
4.1.13 The crate shall host the common CompactPCI Serial backplane (section 2.1) – power and signaling
| cabling, and backplane mounting holes shall be placed accordingly.
4.1.14 The crate shall host front boards (System Board and Peripheral Boards) which are 220mm long.
| Therefore the backplane needs to be mounted 60mm deeper than in regular CPCIs crates.
4.1.15 Each slot of the crate shall have a width of 6HP. Card guide rails shall be mounted accordingly. 4.1.16 220mm card guide rails according to IEEE 1101.10 shall be used. For the System Slot (slot 1) a red
| guide rail shall be used (e.g. Schroff P/N 64560-091), while for all Peripheral Slots (slot 2-9) gray
| guide rails shall be used (e.g. Schroff P/N 64560-092).
4.1.17 The crate shall leave 100mm of rear space behind the backplane for optional rear transition
| modules or an expansion backplane. The mechanics of the crate shall provide metal supports for
| the 100mm card guide rails for optional rear modules. However, these rails shall not be mounted.
4.1.18 The crate shall provide mechanical mounting and cabling of the monitoring components specified
| in section 0.
4.1.19 The Utility(PSU) connector of the main backplane shall be connected using a ribbon cable with
| the Utility connectors of both power backplanes (Figure 12).
4.1.20 Two 230V AC IEC power entry sockets with a fuse and EMC filter shall be placed in the back of the
| crate (Figure 10) and wired with FASTON terminals to the front panel (Figure 12). These power
| entry modules shall be compatible with a locking mechanism to prevent accidental removal (e.g.
| V-Lock from Schurter, IEC-LOCK from Schaffner).
4.1.21 The earth screw shall be placed in the back of the crate and connected to earth contacts of 230V
| AC IEC power sockets as depicted in Figure 12.
4.1.22 The cabling of the crate shall be done according to wiring diagram in Figure 12.
4.1.23 All outer covers of the crate (top, bottom, left, right, front, back) shall be powder coated with
| color RAL XXXX (TBD influence on EMC).

### 4.2 Front panel

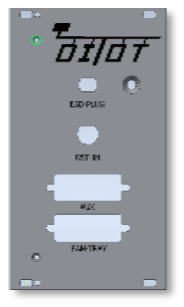
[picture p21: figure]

Figure 11: Crate front panel

The front panel module (Figure 11) shall be compliant with the following characteristics:

4.2.1 The front panel shall be installed on the right side of the crate, next to the power supplies (Figure
10) and have a width of 14HP.
4.2.2 | The front panel shall be equipped with an EMC gasket.
4.2.3 | The front panel shall host an ESD plug for connecting ESD bracelet when manipulating the boards,
| a BNC connector for external power cycling, a fan tray connector and an AUX connector.
4.2.4 | The fan tray connector shall be a female 15-pin DSUB with screws preventing accidental removal
| (Amphenol 53611-G16-8LF). It shall be connected through a ribbon cable to the fan connector in
| the main backplane (pinout specified in Table 3).
4.2.5 | The Front AUX connector shall be a female 15-pin DSUB with screws preventing accidental
| removal. It shall be connected to the signals arriving from the 4-pin Back AUX connector (wired to
| the AUX connector on the main backplane) and 12V arriving from the fan tray connector according
| to Table 9.
4.2.6 | The BNC connector can optionally input an external signal (5V TTL, active high) that is used for
| power cycling the crate. It shall drive a relay connected in series with the power button to break
| on request the 230V AC power going to the power supplies.
4.2.7 | The aforementioned components shall be placed on a PCB screwed to the metal plate of the
| front panel to ensure proper and reliable mounting.
Signal | Front Aux pin | Back Aux pin | Signal | Front Aux pin | Back Aux pin
GND | 1 | 1 | PRST# | 4 | 4
+5V | 2 | 2 | GND | 5 | 1
PWRBTN# | 3 | 3 | +12V | 6 | --
Table 9: Front panel Aux connectors pin assignment

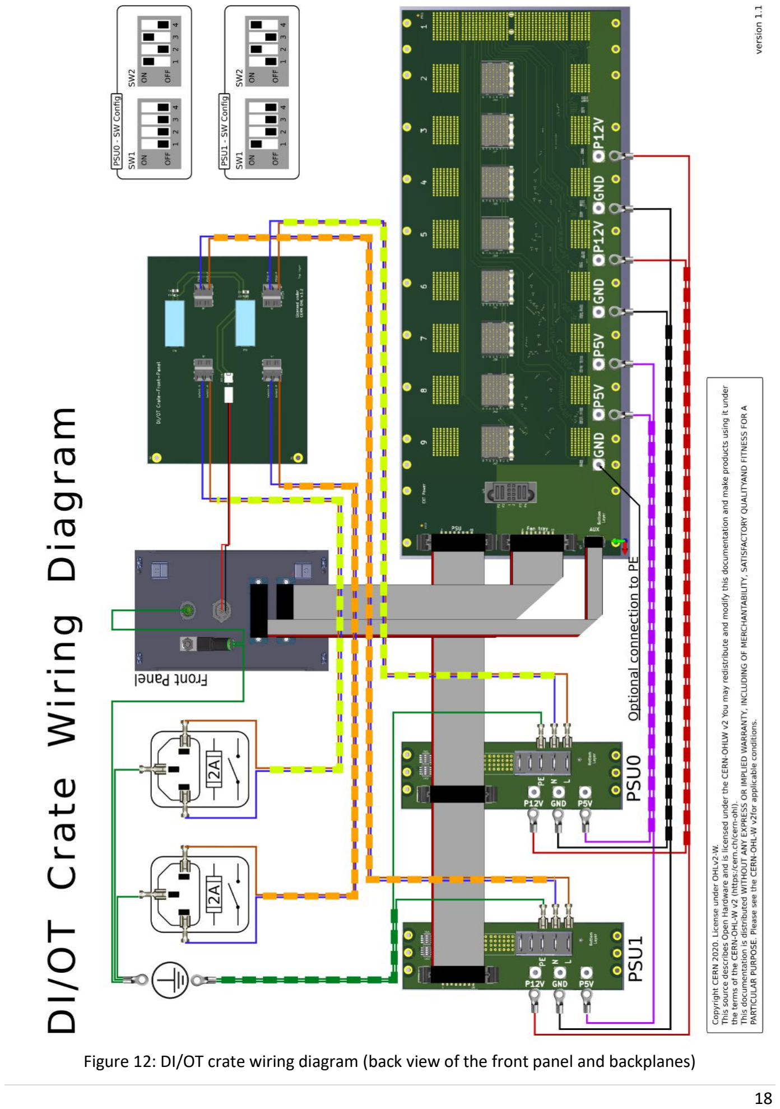
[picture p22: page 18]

Figure 12: DI/OT crate wiring diagram (back view of the front panel and backplanes)

## 5 Fan tray

Developed by: BE-CO with equipment groups or off-the-shelf fan tray

The fan tray is an additional module to the main 3U CompactPCI Serial crate. It could be placed in the rack, below or above the 3U crate for systems that require better heat dissipation (e.g. deployed in radiation-free areas). Either an off-the-shelf 12VDC powered or a custom made fan tray can be used. The custom made fan tray shall contain BLDC (Brushless DC) fans, temperature sensors and a monitoring module (the same one used for power supply monitoring) and should meet the following requirements:

5.1.1 | The fan tray’s height shall be 1U (1 rack unit)
5.1.2 | The fan tray’s width shall be 19”.
5.1.3 | The fan tray shall be equipped with rack mounting holes and front handles
5.1.4 | The placement of fans inside the fan tray shall be such to provide air flow for all the front cards
| and the power supplies.
5.1.5 | The fan tray shall receive power and control signals through a 16-pin IDC connector (with latches
| to prevent accidental removal) from the main 3U chassis. The fans inside the fan tray shall be
| powered from +12V and the monitoring module from +5V. There is no additional power supply
| mounted inside the fan tray.
5.1.6 | The fan tray shall draw not more than 36W from the +12V power provided by the IDC connector.
| Note: This estimation is a safe upper limit based on the current that can be provided over the IDC
| connector (1A per-pin, current pinout of the connector in Table 3 dedicates 4 pins to provide +12V
| power). It can be reached in radiation-free areas where powerful, off the shelf PSU is used (e.g.
| 300W). In radiation-exposed areas the fan tray is expected to draw not more than 10-15W.
5.1.7 | The fan tray shall host a monitoring module (the same one as used for power supply monitoring,
| see section 8.2 for details) that communicates with the System Board of the 3U crate over a
| PMBus interface.
5.1.8 | The pinout of the front connector of the fan tray shall be identical to that of the IDC connector
| exposed on the front panel of the main 3U crate (see Table 3).
5.1.9 | The fan tray shall feature a fully passive board hosting a front IDC connector, fan connectors and
| pin headers to plug the monitoring module.
5.1.10 The fan tray shall ensure air flow at the level of 360 CFM (Cubic Feet per Minute) (three fans
| each providing 120 CFM) - TBD further simulations are ongoing.
| Note: This is based on DI/OT proof of concept off-the-shelf crate. Thermal simulations to be
| done, to determine what’s the sufficient minimum air flow, especially that in radiation-exposed
| areas the main power supply can provide 100W total power (comparing to 300W outside
| radiation).

## 6 System Board

Developed by: BE-CO with equipment groups


Figure 13: DI/OT System Board example

The common Distributed I/O Tier System Board (Figure 13) is the main FPGA-based board in the DI/OT crate. It is the main crate controller that communicates with application-specific peripheral boards, fieldbus mezzanine and is responsible for crate monitoring. The project foresees a design of two variants of the system board (radiation-tolerant and non-radiation-tolerant) of the following characteristics:

6.1.1 | The board’s dimensions are 100mm x 220mm x ≤ 6HP
6.1.2 | The board shall be equipped with an LPC FMC connector to host a communication mezzanine.
6.1.3 | In addition to point 6.1.2, the non-radiation-tolerant variant of the system board shall connect 3
| of the HPC gigabit transceiver interfaces to the FPGA to support in total 4 high speed transceivers
| of a communication mezzanine.
6.1.4 | The board may host any other (not only communication) LPC FMC mezzanine if required by the
| application.
6.1.5 | The FPGA selection for radiation-tolerant variant shall be made between a Flash-based FPGA (e.g.
| SmartFusion2) and a radiation-hard SRAM-based NanoXplore FPGA (NG-Medium).
6.1.6 | The non-radiation-tolerant variant shall feature a System-on-Chip (e.g. Xilinx Zynq/Zynq
| Ultrascale). A more powerful unit is required outside radiation since for those applications
| equipment groups will be implementing more complex data processing.
| Note: If a DI/OT installation spans across both radiation-exposed and radiation-free areas, one
| can also use the radiation-tolerant variant of the System Board in radiation-free areas to keep the
| whole system homogeneous.
6.1.7 | The board shall have a set of 6 Airmax connectors (P1 – P6) to communicate with the DIOT
| backplane, following the CompactPCI Serial specification PICMG CPCI-S.0 [1] (see table below).

Designator | Rows | Pins | Walls | P/N
P1 | 6 | 72 | 4 | 10052825-101LF
P2, P3, P4 | 8 | 96 | 2 | 10052837-101LF
P5 | 6 | 72 | 2 | 10052824-101LF
P6 | 8 | 96 | 4 | 10052838-101LF
6.1.8 | The pinout of the P1 – P6 Airmax connectors shall be compatible with the CompactPCI Serial
| specification PICMG CPCI-S.0 [1], with the difference that all the PCIe, USB, SATA, Ethernet lanes
| are used as general purpose differential lanes for simple communication with peripheral boards
| (e.g. using fast SPI or direct I/O connections).
6.1.9 | The system board shall produce locally, using DC-DC converters and LDOs, voltage levels required
| for the FPGA, FMC mezzanine and all other on-board components.
6.1.10 The FPGA of the System Board shall connect to the 11 general purpose I/O lines (“IO” signals in Table 44 and Table 45 of PICMG CPCI-S.0 [1]) to use them for various monitoring-related
| interfaces (e.g. PSUs PMBus, Fan tray monitoring) according to Table 1.

## 7 Peripheral Boards

Developed by: Equipment groups

### 7.1 Specification

Peripheral boards are the application-specific boards, to be installed in slots 2-9 of the 3U crate. They are designed by the equipment groups to fit a specific application and share some common characteristics to be re-usable between groups:

7.1.1 | The board’s dimensions are 100mm x 220mm x ≤ 6HP
| Note: Peripheral Board can be wider than 6HP, but in that case it will block adjacent backplane
| peripheral slots.
7.1.2 | The board shall use a 72-pin P1 Airmax connector (see table in 6.1.7) to communicate with the
| System Board over the common CompactPCI Serial backplane. The P1 connector provides:
| • Power: +12V, +5V, GND
| • 14 LVDS differential pairs between the Peripheral Slot and the System Slot of which:
| • <slot>_mtx_p/n; <slot>_mrx_p/n – 2 pairs are routed for high-speed
| communication (e.g. MGT FPGA transceivers)
| • <slot>_clk_p/n – 1 pair is routed to provide a low skew clock distribution to this
| slot
| • <slot>_d[0..10]_p/n – 11 pairs can be used for any sort of communication up to
| tens-Mbps (e.g. fast SPI or direct I/O connections).
| • RST_N – a reset line common to all Peripheral Slots.
| • I2C_SCL, I2C_SDA - a service I2C bus, shared between all the slots, used for Peripheral
| Boards identification.
| • SHARED_BUS[0..4] – 5 multi-drop single-ended lines shared between all the slots. Those
| can be used as internal interlock lines.
| • <slot>_SERVMOD_N single-ended signal used for Peripheral Board identification

7.1.3 | In the case of radiation-tolerant variant of the System Board, MGT FPGA transceivers are not used,
| therefore <slot>_mtx_p/n; <slot>_mrx_p/n differential pairs are connected to regular FPGA I/Os
| and can be used for general purpose communication (like <slot>_d[0..10]_p/n).
7.1.4 | Optionally, a P6 Airmax connector can be used if more communication lanes between the
| Peripheral Slot and the System Slot are needed. The P6 connector provides:
| • <slot>_d[11..14]_p/n – 4 LVDS differential pairs between the Peripheral Slot and the
| System Slot that can be used for any sort of communication up to tens-Mbps (e.g. fast SPI
| or direct I/O connections).
7.1.5 | Optionally, a 96-pin P4 Airmax connector (RTM) can be used if direct communication between
| Peripheral Slots is required or if a Peripheral Slot needs an RTM (Rear Transition Module). The P4
| connector provides:
| • Vext1; Vext2 – two voltage levels provided from the external power supply
| • RTM_BUS[0..7] – 8 single-ended lines shared between all the Peripheral Slots. Each line
| can carry up to 0.95A. Those can be used for inter-board communication.
| • RTM_IO[0..47] – 48 pins are routed to the back of the backplane for RTM communication.
7.1.6 | If the functionality of the P4, P6 connectors is not needed, the connectors may not be placed on
| the Peripheral Board.
7.1.7 | The board receives through the P1 connector +12V (main power rail) and +5V (low power standby
| rail) and should produce locally, using DC-DC or LDO, the voltages required to its operation. The
| total power provided by the power supplies for the 12V is 100W (for radiation-tolerant in-house
| designed PSU) and for the +5V is 10W; this includes the consumption of the System Board and of
| the Fan Tray (if needed).
7.1.8 | Auxiliary voltages (e.g. for analog frontend) can be provided through the P4 (RTM) connector (see
| section 2.1).
7.1.9 | The pinout of the P1 (and optionally P6) Airmax connectors shall be compatible with the
| CompactPCI Serial specification PICMG CPCI-S.0 [1] , with the difference that all the PCIe, USB,
| SATA, Ethernet lanes are used as general purpose differential lanes for simple communication
| with peripheral boards (e.g. using fast SPI or direct I/O connections).
7.1.10 If additional shielding is needed (e.g. for an analog front-end), a peripheral board can be housed
| in a 3U cassette.
7.1.11 If a custom application-specific backplane is used, the selection of the connector for peripheral
| boards is up to the designer (e.g. DIN-type connectors can be used if needed).


Figure 14: DI/OT Peripheral Board example

### 7.2 Peripheral Boards identification and remote reprogramming

To ensure the means of identification, each Peripheral Board (and its RTM if available) shall be equipped with I2C EEPROM that could be dynamically attached to the service I2C bus. Peripheral Boards are identified by the system board using the combination of <slot>_SERVMOD_N signal and the service I2C bus. <slot>_SERVMOD_N signal is used to enable Service Mode for a given Peripheral Board. When in Service Mode, Peripheral Board attached I2C EEPROMS to the shared I2C bus and selected backplane I/O lines to JTAG TAP (if the board features an FPGA).

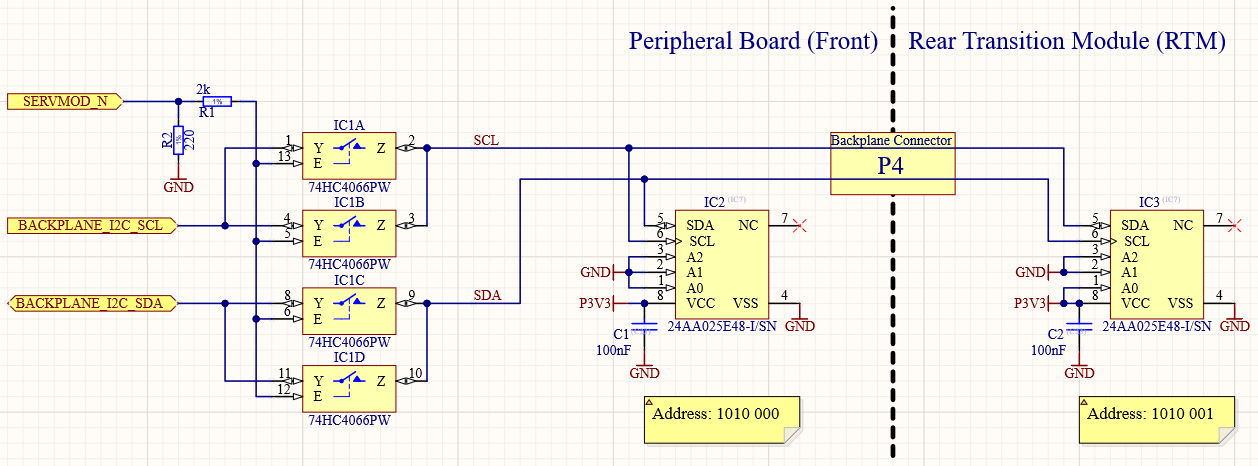
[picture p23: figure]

Figure 15: Circuit required for Peripheral Board identification

Identification procedure:
1. System Board reads <slot>_SERVMOD_N state (low = board inserted in a given peripheral slot)
2. System Board drives <slot>_SERVMOD_N high to attach identification EEPROM/-s to the shared I2C bus
3. System Board reads unique ID and additional information about Peripheral Board and RTM (if present)
4. After the identification cycle is finished System Board releases <slot>_SERVMOD_N for this slot.

Attention: Digital switches and EEPROMs from Figure 15 are not qualified for radiation-exposed applications. TODO: Check EEPROM and digital switch recommendation for radiation-tolerant boards.

Backplane P1 connector pins have dual IO/JTAG function (selectable with <slot>_SERVMOD_N):
- A3 (<slot>_d0_p) – TDI
- D3 (<slot>_d1_p)– TDO
- B4 (<slot>_d2_p)– TMS
- H4 (<slot>_d3_p)– TCK
- K4 (<slot>_d4_p)– nTRST

## 8 Crate monitoring

Developed by: BE-CO with Equipment groups

Monitoring of the DIOT crate is implemented in the main FPGA of the System Board and utilizes 11 general purpose I/O backplane lines to communicate with the power supplies and the optional fan tray. Following the PICMG CPCI-S.0 specification [1], the communication with these modules is based on the I²C interface. According to the standard an I

2C System Management Bus is shared between the power supplies, fan tray, and all the peripheral boards. In the DIOT crate two separate I

2C busses are distinguished:

- I

2C System Management Bus – exposed on the utility connector (as defined in the CPCI-S.0 standard), but connected to the System Slot using 2 of the general purpose I/O backplane lines (see M_SCL, M_SDA lines in Table 1). It is used to read monitoring quantities of the power supplies and the fan tray.
- I

2C Peripheral Bus – shared bus between the System Slot and all Peripheral Slots (utilizes IC_SCL, IC_SDA backplane lines). It is used to read the board ID of each Peripheral Board for autodetection.

### 8.1 Monitored Quantities

In this section the measurements that comprise the readout part of the diagnostics are described.

8.1.1 | For each main PSU, voltage and current monitoring for each of the power rails (12V / 5V) shall be
| provided, along with one temperature (might be worth it to put more, one ambient and two major
| loads, TBD) readout.
8.1.2 | Multiple temperature sensors shall be supported by means of the monitoring modules in the
| PSU(s) and the optional fan tray. These may be mounted on the top or bottom grill, the backplane
| or in otherwise strategic locations, depending on the application.
8.1.3 | Depending on the fan test results (TBD) the user may be able to monitor the speed of the fans in
| the optional fan tray and control the fan set-points.

### 8.2 Monitoring module

Developed by: BE-CO

A monitoring module shall be developed to provide PMBus (I²C–based) monitoring and control for the PSU(s) and the fan tray. It shall be a small form-factor module (Figure 16) that can be mounted on a motherboard.


Figure 16: Mockup of the monitoring module

8.2.1 | When driving fans, the module shall be powered by 12V and 5V power rails. When it is not
| driving any fans, supplying the 5V power rail will be enough (e.g. inside the PSU).
8.2.2 | A reset signal from the FPGA on the System Board shall be provided to the microcontroller in
| case a watchdog fails in radiation-exposed areas and it enters a fault condition (e.g. line P_RST in
Table 2).
8.2.3 | A subset of the PMBus protocol (specified in section 8.4) shall be used to interface with the
| monitoring module. Two pins shall be used to set the module’s I 2C address.
8.2.4 | Voltage and current monitoring of up to three power rails shall be supported.
8.2.5 | Up to three temperature sensors of PT100/PT1000 type (or I 2C, TBD) shall be supported.
8.2.6 | PWM control of up to three 12V fans shall be provided. Up to 1A of current shall be provided to
| each fan.
8.2.7 | If the fans provide a dedicated PWM control pin, the power FET part of the module becomes
| redundant. Thus, a reduced-size version of the module may also be produced (notice the dashed
| line in Figure 16) or jumpers can be added to reroute the 12V so that the same board might be
| physically cut, TBD.
8.2.8 | If the fans provide speed sense pins, speed measurements shall be also made available through
| the PMBus interface.
8.2.9 | An SWD (Serial Wire Debug) programming interface shall be provided through the main
| connector and through an on-board header connector.
8.2.10 Exact details of this module have to remain TBD for now (most probably it will feature
| ATSAMD21G18 microcontroller, radiation tests are ongoing).

### 8.3 Monitoring software services

8.3.1 | CCS
8.3.2 | COSMOS
8.3.3 | Remote reprogramming framework

### 8.4 PMBus for DI/OT

## 9 Customization examples

This section lists examples how the common and modular DI/OT hardware kit can be customized for various applications.

### 9.1 Custom application-specific backplane

Development by: Equipment groups


Figure 17: Custom DIOT backplane

A fully custom backplane may be designed for applications with constrains that cannot be fulfilled by the common DI/OT backplane. Such a custom backplane shall have the following characteristics for compatibility with the DI/OT crate mechanics:

9.1.1 | The backplane shall have a System Slot made of P1 – P6 Airmax connectors and 6HP width, as
| specified in section 2.1 and the Compact PCI Serial PICMG CPCI-S.0 [1] standard.
9.1.2 | The backplane shall have a set of IDC connectors (Utility(PSU), FANTRAY, AUX) as defined in
| section 2.1.
9.1.3 | The backplane shall distribute +12V and +5V power from the main power supply to the System
| Slot and IDC connectors (Utility(PSU), FANTRAY).
9.1.4 | The backplane shall have mounting holes compatible with a common DI/OT backplane (section
| 2.1).
9.1.5 | The backplane shall not be more than 54 HP wide (including the System Slot) in case it has to fit
| in the crate mechanics as defined in section 4.1.
9.1.6 | The rest of the backplane (“Custom space”) can host any application-specific connectors and
| additional signal wiring. It can for example be used to distribute any non-standard auxiliary
| voltages to Peripheral Boards (e.g. for analog front-ends) or to host I/O BNC connectors for
| external sensors/actuators.

## 10 References

[1] PICMG CompactPCI Serial (CPCI–S.0 ) Rev 2.0 https://www.picmg.org/openstandards/compactpci-serial/
(inside CERN only) https://wikis.cern.ch/download/attachments/103445302/PICMG%20CPCI-S.0.pdf
[2] Measurements of power supply ripple and noise for uQDS crate https://wikis.cern.ch/download/attachments/103445337/UQDS_PSU_Ripple.pdf
[3] IEEE 1101.10-1996 standard
https://ieeexplore.ieee.org/document/588320

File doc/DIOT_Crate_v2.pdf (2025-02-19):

------- | 1.0 | DRAFT

# CERN

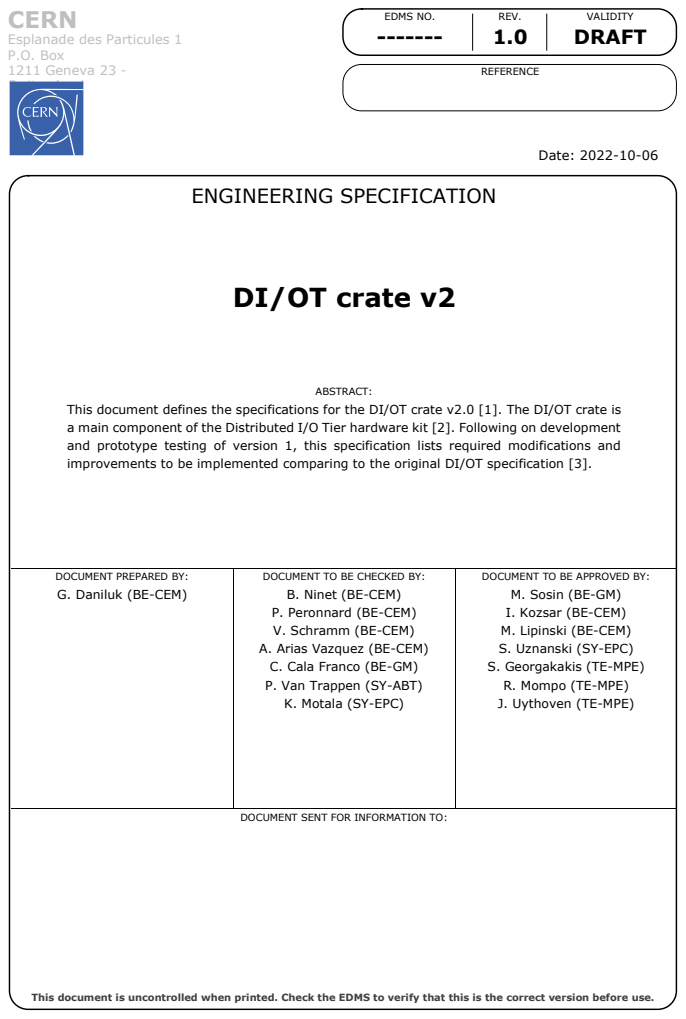
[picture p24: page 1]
EDMS NO.; REV.; VALIDITY; REFERENCE; Date: 2022-10-06; ENGINEERING SPECIFICATION; ABSTRACT:; DOCUMENT PREPARED BY:; DOCUMENT TO BE CHECKED BY:; DOCUMENT TO BE APPROVED BY:; G. Daniluk (BE-CEM); B. Ninet (BE-CEM)

Esplanade des Particules 1
P.O. Box
1211 Geneva 23 -

DI/OT crate v2

This document defines the specifications for the DI/OT crate v2.0 [1]. The DI/OT crate is
a main component of the Distributed I/O Tier hardware kit [2]. Following on development
and prototype testing of version 1, this specification lists required modifications and
improvements to be implemented comparing to the original DI/OT specification [3].

M. Sosin (BE-GM)
I. Kozsar (BE-CEM)
M. Lipinski (BE-CEM)
S. Uznanski (SY-EPC)
S. Georgakakis (TE-MPE)
R. Mompo (TE-MPE)
J. Uythoven (TE-MPE)

P. Peronnard (BE-CEM)
V. Schramm (BE-CEM)
A. Arias Vazquez (BE-CEM)
C. Cala Franco (BE-GM)
P. Van Trappen (SY-ABT)
K. Motala (SY-EPC)

DOCUMENT SENT FOR INFORMATION TO:

This document is uncontrolled when printed. Check the EDMS to verify that this is the correct version before use.

REFERENCE | EDMS NO. | REV. | VALIDITY

Page 2 of 14

## HISTORY OF CHANGES

REV. NO. | DATE | PAGES | DESCRIPTIONS OF THE CHANGES
0.1 | 2022-10-06 | 14 | First version of the doc.
1.0 | 2022-10-20 | 14 | Version 1.0 ready to start design changes

Page 3 of 14

## TABLE OF CONTENTS

Page 4 of 14

## 1. INTRODUCTION

This document defines the specifications for the DI/OT crate v2.0 [1]. The DI/OT crate is a main component of the Distributed I/O Tier hardware kit (Figure 1, [2]). It hosts two redundant power supplies, the DI/OT System Board (SB), up to 8 application-specific Peripheral Boards (PB) and up to 8 application-specific Rear Transition Modules (RTMs).


Figure 1: DI/OT modular hardware kit

Following on development and prototype testing of version 1, this specification lists required modifications and improvements to be implemented comparing to the initial DI/OT specification [3]. The main motivation for these modifications are:

- split of RaToPUS (DI/OT rad-tol power supply) into two modules (front: DC/DC stage; back: AC/DC stage);
- past assembly issues and mistakes in cabling and setting dip-switches configuration on two separate power backplanes.
- requirements coming from new applications like CERN power converters control and Quantum Computing community.

Page 5 of 14

## 2. MODIFICATION OF MECHANICAL DESIGN

Figure 2 presents a conceptual design of DI/OT crate mechanics v2.0. The following modifications shall be applied to the mechanical design with respect to DI/OT crate v1.x:

1. Extended enclosure length to enlarge the space available for RTMs from 100mm to 160mm and Rear Panel PCBs. This way the RaToPUS AC/DC stage can be hosted behind the Power Backplane.
2. Reduced cabling – a 3-board assembly (Main Backplane, Power Backplane, Front Panel) is introduced to distribute power (12V, 5V, GND) and control/diagnostic signals. Appropriate connectors are proposed in a dedicated section for each of these boards.
3. Addition of back panel PSU slots that plug directly into the Power Backplane. This space shall replace 230VAC sockets of version 1.x and be used to host either:
a. for non-rad-tol DI/OT variant: Back Panel PCB (described in the next section);
b. for rad-tol DI/OT variant: AC/DC stage of RaToPUS (specified outside the scope of this document).
4. 230VAC relays moved from the Front Panel PCB to the Back Panel PCBs. This way all 230VAC circuits are kept in the back of the crate.
5. Merge two instances of Power Backplane v1.0 into a single PCB (Dual Power Backplane).
6. Dual Power Backplane shall be held in place using a short horizontal rail that does not disturb air flow through front boards (https://ohwr.org/project/diot-crate-hw/issues/36). (https://ohwr.org/project/diot-crate-hw/issues/36)
7. Power Backplane shall be covered in the front with a Formex insulation sheet, to prevent exposure of 230VAC through-holes to a user.
8. Modified placement of PSUs to ensure 4HP spacing between two modules at a cost of the front panel size reduction (from 14HP to 10HP).
9. Cable connection of PE terminal block on the Power Backplane to the chassis.


Page 6 of 14

Figure 2: DI/OT crate mechanics v2.0

Page 7 of 14

## 3. MODIFICATION OF PCBs

With respect to DI/OT crate version 1.0, all PCBs: Main Backplane (MB), Power Backplane (PB), Front Panel (FP) shall be modified. Additionally, a new board is introduced: Back Panel PCB. The sections below list modifications that need to be introduced to all these designs.

### 3.1 Main Backplane

1. Additional (LVDS15_P/N) differential pair for each Peripheral Slot to communicate with the System Slot. In each Peripheral Slot pins E2, F2 of connector P1 shall be used. In the System Slot, rows 5, 6 of connector P2 shall be used.
2. Additional RTM connector P3, for each Peripheral Slot, providing 56 GPIO pins between a Peripheral Board and an RTM and 2 supplementary voltage levels distributed over row 1 of the P3 connector. For this reason, similarly to the P4 routing, two power planes (Vaux3, Vaux4) shall be created in the P3 space of the
backplane | and | connected | to | P3 | pins | according | to | Table | 1.
Pin | A | B | C | D | E | F | G | H | I | J | K | L
3-08 | GND | I/O | I/O | GND | I/O | I/O | GND | I/O | I/O | GND | I/O | I/O
3-07 | I/O | I/O | GND | I/O | I/O | GND | I/O | I/O | GND | I/O | I/O | GND
3-06 | GND | I/O | I/O | GND | I/O | I/O | GND | I/O | I/O | GND | I/O | I/O
3-05 | I/O | I/O | GND | I/O | I/O | GND | I/O | I/O | GND | I/O | I/O | GND
3-04 | GND | I/O | I/O | GND | I/O | I/O | GND | I/O | I/O | GND | I/O | I/O
3-03 | I/O | I/O | GND | I/O | I/O | GND | I/O | I/O | GND | I/O | I/O | GND
3-02 | GND | I/O | I/O | GND | I/O | I/O | GND | I/O | I/O | GND | I/O | I/O
3-01 | Vaux3 | Vaux3 | GND | Vaux3 | Vaux3 | GND | Vaux4 | Vaux4 | GND | Vaux4 | Vaux4 | GND
Table 1: Peripheral Slot P3 (RTM) connector pinout
3. Fan Tray, Utility and Aux connectors shall be replaced with a single press-fit Utility connector to interface with the Front Panel PCB. Over that same connector also power (12V, 5V, GND) is provided to the Main Backplane. The connector shall provide a mix of power and signal lines: 9P, 24S (9 power contacts, 24 signal contacts). FCI PwrBlade 51940-650LF with pinout is proposed in Table 2.
P1 | P2 | P3 | P4 | P5 | RTN_Sense | P12V_Sense | PS_ON_N | PWRFAIL_N | P_PRES0 | P_PRES1 | P6 | P7 | P8
| | | | | D1 C1 | D2 C2 | D3 C3 | D4 C4 | D5 C5 | D6 C6 | P9 Vaux1
| | | | | GND | M_SCL | GND | P_IO0 | GND | P_IO1
| | | | | B1 | B2 | B3 | B4 | B5 | B6
| | | | | M_SDA | F_IO0 | F_IO1 | P_IO2 | P_RST | GND
| | | | | A1 | A2 | A3 | A4 | A5 | A6
| | | | | GND | F_RST | GND | PWRBTN_N | GND | PRSTN

Vaux2

Vaux3

Vaux4
+5V

GND

GND

+12V
+12V

Table 2: Main Backplane Utility connector pinout

Page 8 of 14

4. Vaux1-4 power planes can be used to distribute to all Peripheral Boards four, low power voltages referenced to common GND. Alternatively, Vaux2 and Vaux4 can be used as galvanically separated GNDaux planes. In this case Vaux1 is referenced to GNDaux1 (Vaux2) and Vaux3 is referenced to GNDaux3 (Vaux4).
5. Leave rectangular power terminals as an alternative.
6. Ext PSU connector shall be expanded to accommodate two additional auxiliary voltage levels (Vaux3, Vaux4).
7. The length of the backplane shall be extended to fit the 3-board assembly (Power Backplane, Front Panel PCB, Main Backplane) in Figure 2. This might require displacement of the current Ext PSU connector in the back of the MB to avoid collision with the new Utility Connector in the front.

### 3.2 Power Backplane

1. Two instances of the Power Backplane v1 shall be merged into a single PCB.
2. Ensure 4HP spacing between front power supplies.
3. Replace PSU connector FCI PwrBlade 51940-473 with a non-faston, fully press-fit variant FCI PwrBlade 51940-650LF
4. Add 2 connectors to receive AC or DC current from Back Panel PCBs. E.g. FCI PwrBlade 51940-581LF or TE 2-6450550-4. See Table 3 for example connector pinout. In that pinout all AC (L, N, PE) and DC (DC_IN, DC_RTN) power inlets shall be directly wired to appropriate contacts of the FCI PwrBlade 51930-473. DC_IN and DC_RTN are used in case of full DC powering for a DI/OT crate is required (e.g. 24VDC or 48VDC).
5. Each back panel connector shall feed directly one front PSU slot, i.e. input AC/DC current lines from two PSUs cannot be connected together.
6. Place back panel connectors to host 12HP back modules.
7. Route BNC power-cycle request received from the Front Panel to both Back Panel connectors. See Table 3 and Table 4 for reference pinout.
8. Remove DIP switches.
9. Connect CUR_SHARE signal between two PSUs through a 0R resistor, mounted by default.
10. Add a weak pull-down on PS_ON_N signal to ensure the system is powered even if
running | without | a | System | Board | (https://ohwr.org/project/diot-crate-
hw/issues/56). (https://ohwr.org/project/diot-crate-hw/issues/56)
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

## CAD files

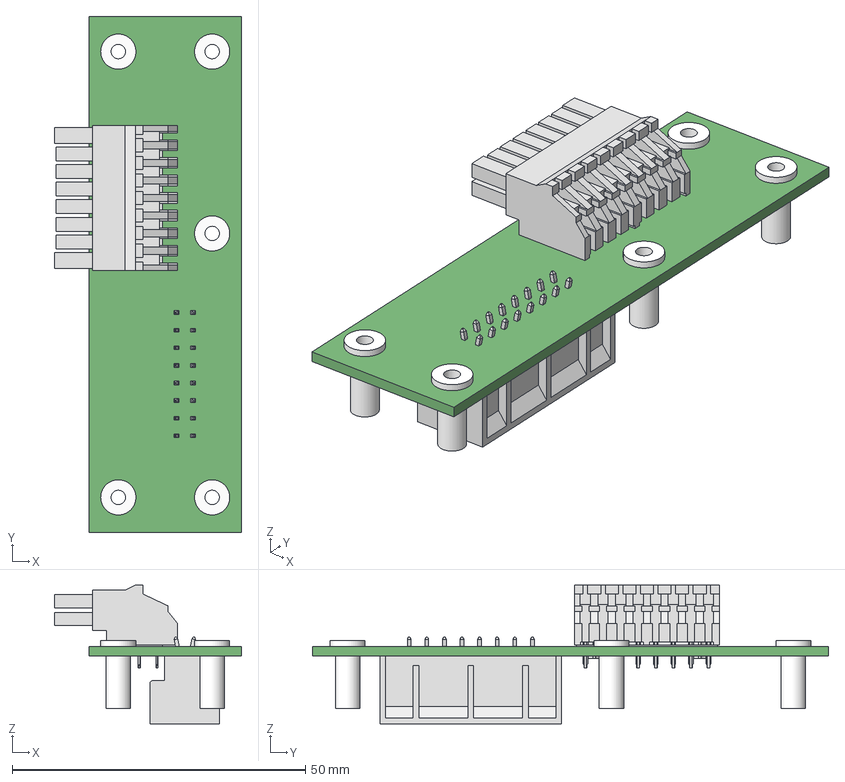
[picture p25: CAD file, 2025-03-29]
Models/Helper#1-A01.iam.v1.stp
31.9 x 88.0 x 23.7 mm
9775106360R x 5

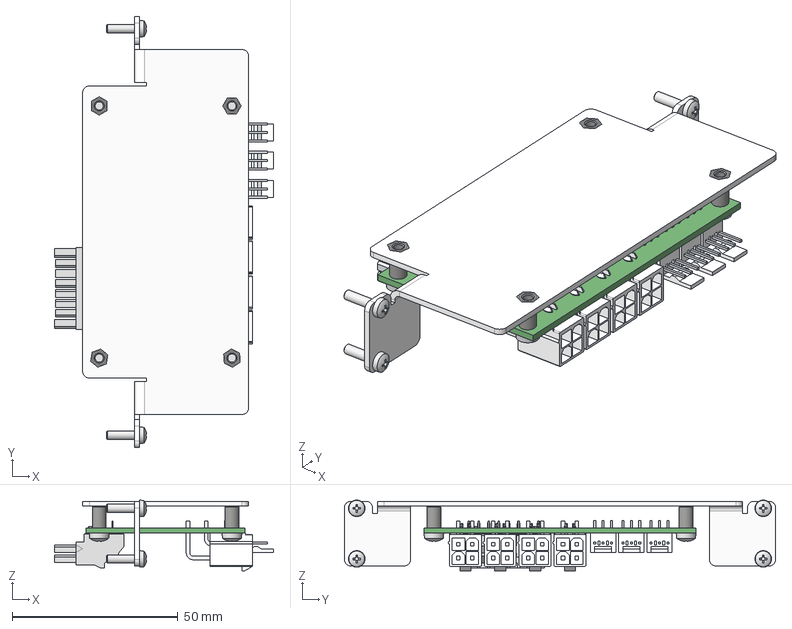
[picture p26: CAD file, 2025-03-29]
Models/Helper#2.iam.v1.stp
66.0 x 130.0 x 21.4 mm
MOLEX_39-30-0040 x 4
MOLEX_22-05-7038 x 3
SO-M3-8 ZI x 4
DIN 7985 (Z) - M2,5x10-Z x 4
DIN 7985 (Z) - M3x8-Z x 4

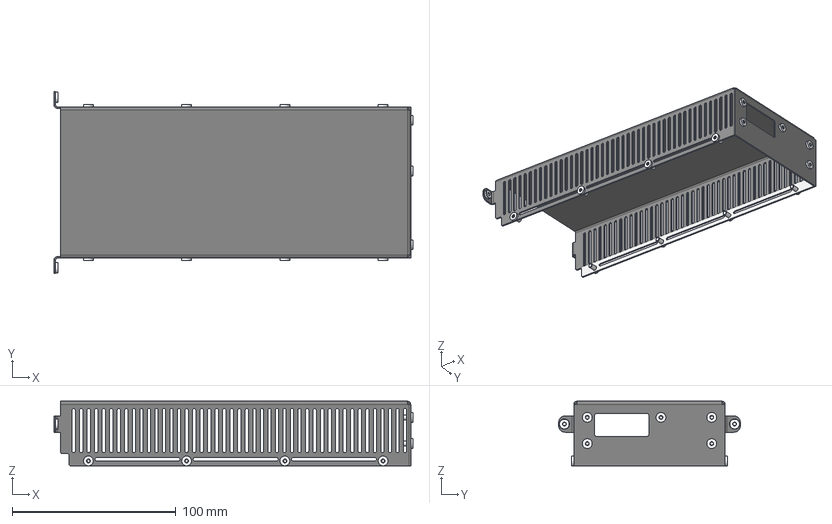
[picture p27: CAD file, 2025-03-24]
Models/DIOTPSU-A02.iam.v1.1.stp
219.3 x 111.0 x 39.5 mm
DIOTPSU-A02-P01_1
S-M2.5-1 ZI x 2
M3x6 BOSSARD BN9524 x 13

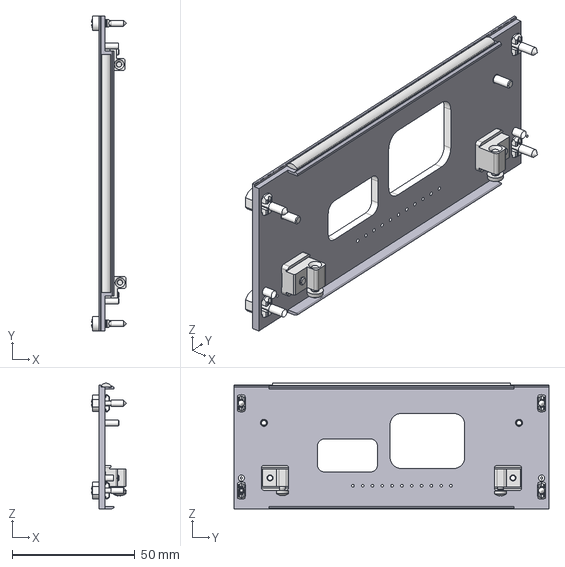
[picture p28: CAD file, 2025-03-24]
Models/DIOTPSU-A01.v1.stp
14.2 x 128.4 x 51.2 mm

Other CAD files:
Models/DIOTPSU-A02.v1.stp

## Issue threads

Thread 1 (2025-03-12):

Primary project review

martafafara, 2025-03-12:
I've analyzed the design and I have some remarks.

**Schematic**

- [ ]  capacitors C9 and C10 should be 2.2nF
- [ ]  C11 is not necessary
- [ ]  No pull-ups on Open Drain outputs of IC5 (pins: 5, 7, 6, 14). R6 may play a role of pull-up, but not sure if it is comprehensive

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

- [ ]  Consider input filter for IC4
- [ ]  No EEPROM predicted
- [ ] No filtering diode at the the board entry (DIOT commonly use PRTR5V0U2X)
- [ ] The power ports P5V and P5V0SB should be connected?

**PCB**

- [ ] I2C lines are parallel - consider its separation

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

- [ ]  Capacitors C9 and C10  hang next to the track, that should rather pass through its pads. It could be good point to separate traces.

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

- [ ]  Power supply filtering capacitor should be as close to the power pin as possible

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

- [ ]  T connection on the Bottom side is not necessary here

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

- [ ] Measuring traces should avoid passing under coils

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

- [ ]  Between measuring traces should be GND

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

- [ ] DRC could be cleared
- [ ]  DIOT logo and PCB description will be hidden if PSU module is assembled
- [ ] J12 description is not clear
- [ ] Lack of ESD strip

Misio666, 2025-03-15:
- "logo and PCB description will be hidden if PSU module is assembled"
PSU board, Mezzanine board and housing will cover the PCB logo anyway. I can move logo to bottom

- "Lack of ESD strip":
There was no ESD strip in the template design and reference projects

martafafara, 2025-03-17:
- no information about cover occurs in schematic or in project description. If cover predicted, junctions J2, J4, J12 and P2 will be hard to use. In the description the integration with Interface Board is mentioned, but project do not contain any connectors necessary.  In fact descriptions placement doesn't matter in this situation.
- The ESD strip occurs in few locations -  [DIOT wiki](https://ohwr.org/project/diot-sb-zu/-/wikis/home) , base system board that is there listed and in the newest [Kasli-DIOT](https://github.com/sinara-hw/KASLI-DIOT) project .

Misio666, 2025-03-31:
I have placed the latest version in the repository; please review it again. I have done my best to implement almost all of the suggested fixes. What still remains is replacing the D4 part number and the R40 resistor with ones that have a lower power rating

gravelpitman, 2025-04-01:
I advise delaying the review process, as mechanical modifications may still be necessary. The current stage is premature for final evaluation.

gkasprow, 2025-04-01:
No way. We must produce as it is.

gkasprow, 2025-04-01:
We must finish thermal tests of the new DIOT crate in 3 weeks!

gravelpitman, 2025-04-01:
To clarify, are we discontinuing development of the 9HP DIPSU version for the 63HP crate?

gkasprow, 2025-04-01:
The problem is that the mechanical review takes far too much time, and we've internal deadlines. We must proceed with the current version and all other fixes left for next revision

martafafara, 2025-04-09:
Second loop of review.

- [ ]  no ESD diode at I2C
- [ ] excessive I2C pull-up - doubled in reference to system boards
- [ ] not filled schematic sheet tables (author, project etc)

- [ ]  I2C traces changes its reference plane GND and P12V0

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

- [ ] Jumper is too small. R42 has case 0603 which has power derating 0.1W (20mA@5V). This value do not corresponds with desgined trace

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

- [ ] minor: symmetrical placement do not meets the shortest capacitor connector

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

- [ ] The input of INA has filter , but the output signal goes around whole board collecting potential noise. Such long trace may also be a meaningful voltage drop - to be verify and potentially consider while divider resistor values set

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

As for now I have no important improvement remarks.

martafafara, 2025-04-18:
D3 and D5  changed to not mounted in default variant. C18 do not occur in newer version of DISPU. I'm not convinced to replace to inductor by resistor. The restistors replaced according to suggestion.

gkasprow, 2025-04-18:
We have clean 3v3 from LDO, we don't need any additional filtering.
Moreover, pure LC filtering without damping makes more harm than good.

martafafara, 2025-04-22:
Alternate part for L1 and L2 are prepared in Default variant.

martafafara, 2025-05-14:
C1 is obsolete. Proposed replacement: [RNS1A101MDN1KX](https://www.digikey.pl/pl/products/detail/nichicon/RNS1A101MDN1KX/3768607)

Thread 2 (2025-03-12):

third fan tacho

jordens, 2025-03-12:
Any chance to get a second max6639 on there to drive and monitor tacho of the third chassis fan?

See https://github.com/sinara-hw/DIOT_power_module/issues/1 which I think should have been the original repo for this project.

jordens, 2025-03-26:
I think this has been resolved in the last commits, thanks @Misio666!

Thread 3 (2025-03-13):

Mechanical Issues

gravelpitman, 2025-03-13:
**1. Incorrect PCB shape and mounting holes spacing**

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
Please use this PCB shape.

**2. LED Posiotion**
Because of the incorrect PCB shape, the LEDs are too far from the front panel (FP) and will cause light leakage.

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

**3. There are no chamfers at the back end of the PCB.**

**4. Concerns regarding the use of an M5 bridge for connecting the LOP-400-12 to the PCB.**

- If you want to use the M5 bridge as shown in the Altium schematics, the bolt spacing is incorrect. A spacing of 20 mm is required, but the current spacing is approximately 17.9 mm.  In my opinion, there is not enough space along the X-axis to move the J7 and J11 connectors to achieve 20 mm bolt spacing.

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

- Using M5 brackets requires good height alignment along the Z-axis between the LOP-400 connectors and the J7 & J11 bolting plane. Otherwise, bent bridges may be needed.

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

- If we want to use some kind of sheet metal bracket to connect this connector, I would recommend a custom one with a fork-style connector on one side. Such a solution would not require completely unscrewing the screw from the Mean Well PSU and would allow for greater tolerance in X-axis bolt spacing mismatch.

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

**5. Why are the fan connectors duplicated?**
I would leave only goldpin connectors for the fans. We are seriously limited regarding space, so why duplicate the same connectors? By keeping only goldpin connectors, we could fit connectors for three fans.

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

**6. Suggestions regarding the layout, mezzanine, etc.**
Assuming the removal of the duplicated fan connectors, I would change the layout of the connectors and the shape of the boards. This would make it easier to fit everything.

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
Changes on the mezzanine: the P1 connector, transistor T9, capacitor C1 were moved, the cutout for the fan connectors was removed, and the screw holes were repositioned. The entire board was shortened along the X-axis by approximately 4 mm. These modifications will allow the Mean Well power supply to be shifted by about 4 mm in the X- direction, giving us more space at the back of the board for the Molex 4-pin power connectors, fan connectors (goldpin), and so on. This will also make it easier to design an enclosure for the entire power supply, as all connectors requiring access will be located at the back of the board and will not be obstructed by the enclosure

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
With a semi-transparent box, I marked the approximate area that I would cover with the enclosure.

**7.The mezzanine has incorrect spacers**
They should be lower because, in the current version, there is only ~0.4 mm of clearance above it, leaving insufficient space for the enclosure. You could use part number 9775051360R instead.

gravelpitman, 2025-03-13:
**Additional suggestion regarding the enclosure.**
We could use Wurth 7466313  (https://www.we-online.com/en/components/products/WP-SMRA_PINS?sq=7466313R#7466313R) as brackets for mounting the housing. This would vastly simplify the enclosure.

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

Above is a suggestion for the placement of the brackets. Assumption: the enclosure is made of 1 mm thick sheet metal, using M3x6 BOSSARD BN9524 screws (screws with a very low head). The above spacing ensures mountability in the rack and provides a simple hole pattern.

jordens, 2025-03-13:
@gravelpitman Where do the first two images come from? That looks like an interesting and useful document.

* Regarding the fan connectors, it should be something snapping, not just goldpins. But yes, just one connector per fan is sufficient
* Also note that the PCB bottom has 1HP more space than a usual module. Right-angled fan connectors with snaps would fit fine there as well.

@gkasprow could you move https://github.com/sinara-hw/DIOT_power_module/issues/1 here and delete the other empty repo? I think its a duplicate.

As a sidenote: if anyone wants to play with the DIOT mechanics, I collected some models in [this design](https://cad.onshape.com/documents/5d3d4cfe08b60a7a27fda6d0/w/e2d65541d7c5d4b50492d3cd/e/fa418c2cd3d65e7af048db5e)

gravelpitman, 2025-03-14:
@jordens That’s our (Technosystem) internal Sinara/DIOT electromechanical guideline, which I’ve made in cooperation with our electronic designers. It will be released somewhere on GitHub soon.

gravelpitman, 2025-07-24:
I'm closing this issue because a completely new version of the PCB has been created, making this issue no longer relevant.

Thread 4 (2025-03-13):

Fan unit connection and case design

kaolpr, 2025-03-13:
**Assumptions:**

- we have fans in the crate we want to control with this module,
- we want to preserve ability to pull this module out from the create without disconnecting any cables,
- we have 20 HP of free space in crate that can be used to accommodate non-DIOT Sinara modules (e.g. Stabilizer or Thermostat), but they need power, so we want to somehow expose power from this module to those extensions,
- this module should be closed in full case on the top side to secure parts with AC against user contact.

**Suggested solution:**

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

- DIPSU - DIOT Integrated PSU
- As @gkasprow suggested, we create two helper PCBs. One (yellow) is mounted to the top-inside of the DIPSU case. There is an angled connector on it that connects to the second helper PCB (violet) that is screwed in parallel with the Backplane and hosts fan connectors and connectors for non-DIOT Sinara modules.
- The case is very much like the case for EEM PWR MOD AC (openings on longer sides for the airflow and cutout on the back for board to board connector (yellow-violet). However, compared to EEM PWR MOD AC it covers only top of the DIPSU as mains is only there (it is not present on the main PCB).

jordens, 2025-03-13:
Yeah. Nice idea to make it pluggable.

* But how do you mount Helper-PCB-2 exactly? The way you have drawn it, it interferes with the crate rails. There is a bit of space (4 HP) next to the backplane that could be used though.
* I'm worried that this narrow "fan/power backplane" will not be rigid enough. Maybe it could work rotated parallel to the PSU PCB and mounted using some (custom) angle brackets to the backplane rails.
* Meeting the alignment tolerances to the two connectors on different PCBs at the same time is likely tricky.
* Note that it will always interfere with the rightmost peripheral on insertion/removal.

kaolpr, 2025-03-14:
> But how do you mount Helper-PCB-2 exactly? The way you have drawn it, it interferes with the crate rails. There is a bit of space (4 HP) next to the backplane that could be used though.

It depends on how we mount backaplane, more specifically if the horizontal rail will be on the top or bottom side of the backplane. But we can also use the space right to the backplane.

> I'm worried that this narrow "fan/power backplane" will not be rigid enough. Maybe it could work rotated parallel to the PSU PCB and mounted using some (custom) angle brackets to the backplane rails.

Yeah, this may be an issue. But I'd leave it to the mechanical designer. There are couple of options, we could do it according to your suggestion or f.e. add some stiffening element on the PCB.

> Meeting the alignment tolerances to the two connectors on different PCBs at the same time is likely tricky.

Yes, and I think we should use connectors that have some flexibility that would allow for minimal alignment when mating.

>  Note that it will always interfere with the rightmost peripheral on insertion/removal.

Yes, but this is also true for original DIOT. However, in original crate removing front interface board requires a lot of effort...

jordens, 2025-03-14:
> It depends on how we mount backaplane, more specifically if the horizontal rail will be on the top or bottom side of the backplane.

Since the PCB guide rails clip into it, isn't there always a horizontal rail in the way?

kaolpr, 2025-03-14:
Yes, you're right! Then we have to move right or explore solution perpendicular to the backplane.

jordens, 2025-03-17:
Oh. You could just use the 4 HP space next to the rear "AUX" PSU slot, i.e. the "RTM" to your helper PCB 2. It has the space, doesn't need any new mechanics, doesn't encroach on any existing module and would itself be extensible/pluggable. No mini fan backplane needed.

kaolpr, 2025-03-17:
You mean Ext PSU? There are not enough common lines between Utility and Ext PSU (only Vext1..4). At least assuming we want to have more than two fan channels that are capable of closed loop control.

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

jordens, 2025-03-17:
Next to the EXT PSU (which is 6 HP). In the CERN DIOT layout those 4 HP RTM space (opposite the 10 HP front interface module) are used by the rear power entry modules (2x 12 HP).

gravelpitman, 2025-03-20:
I spent some time trying to fit everything together. I managed to create mockups of the Helper#1 and Helper#2 boards, including the selection of connectors, as well as the design of the enclosure and front panel for the entire module.

Below, I present the results of my work. The enclosure and the Helper#2 board, along with the bracket securing it to the rear rail, are not the final version.

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
I checked the alignment with the crate; it should work. Please disregard the PowerBackplane visible in the screenshots. In the future, I will prepare a model of the entire Desktop crate with the DIOT Backplane.

To complete this power supply:

- Please arrange the WP-SMRA SMT brackets as shown in the drawing below.

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

- Add the Molex 444321601 connector and position it as shown in the drawing below. This connector will be used to route signals for fan control, as well as 2 pins for +12VDC and 2 pins for GND for power supply. One pin of this connector can handle a maximum current of 8.5A, allowing us to deliver approximately 17A to the Helper#2 board.
- Move the connectors J7 and J11 as shown in the drawing.
- Reposition the power supply spacers (Wurth 9775066360) according to the drawing below.
- Move the J12 connector roughly as shown in the drawing; its position is not highly critical.

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

In the compressed folder below, I have added a 3D model of the front panel with cutouts and a file for the enclosure. The files are prepared to be easily imported into Altium. Simply place them at position X=0 and Y=0. At least, that should work if I did it correctly :D
[Enclosure +FP.zip](https://github.com/user-attachments/files/19368864/Enclosure.%2BFP.zip)

jordens, 2025-03-20:
Is the BMI helpful? Misalignment will now lead to massive stress/strain instead of mating failure. Not sure if that's better. And the BMI feature on the main-PCB-helper#2 Molex pair doesn't seem to be needed at all.

The space on that mini power backplane appears insufficient for a useful number of at least four 12V and three fan connectors. A proposal to transparently support the "RTM" solution I explained above: Could you move the Molex BMI header on helper #2 that pokes through the enclosure to a Z position (in your coordinate system) and orientation such that it can mate with a right angle Molex receptacle 447641602 on a "RTM" at +5 HP offset from the main PSU PCB? That's a mating plane center at Z = 5*5.08+4.44+3/2 mm = +31.34 mm above the main PCB (crate right) and oriented such that pin 1 on Y+ (crate top). If that doesn't work, the alternative is mating plane center at Z = 7*5.08-1.6-4.44-3/2 = +28.02 mm and pin 1 on Y-.

kaolpr, 2025-03-24:
Sorry @jordens, but neither @gravelpitman nor I understand your idea. Can you please make some sketch or something and paste it here?

jordens, 2025-03-24:
[This](https://cad.onshape.com/documents/5d3d4cfe08b60a7a27fda6d0/w/e2d65541d7c5d4b50492d3cd/e/fa418c2cd3d65e7af048db5e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) would be my preference corresponding to the first location described:

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

Place the fan connectors and the 12V connectors on that "PSU RTM".

The alternative would be placing the PSU RTM guides 2HP to the right (X+ in the cad coordinate system, Z+ in your coordinate system) and the right angle molex on the PSU RTM bottom. But it's worse.

jordens, 2025-03-24:
There is an argument to be made for supporting short racks without any RTM space. Also for that case I'd prefer mounting the little backplane in-plane with the PSU main PCB. That would be your proposal, but with the little backplane rotate like in my sketch above and with a slightly different sheet metal bracket.

kaolpr, 2025-03-24:
Great, thank you for clarification.

We really don't see definitive advantages of your approach.

We strongly opt for a metal bracket, as having "RTM", as you noticed, will depend on the crate depth, and we want it to be compatible both with full-depth DIOT crate and smaller desktop versions. Also, in short crates, we will not have horizontal rails behind the main backplane.

> In any case I would try to support connector locations such that the backplane (or PSU RTM) can be mounted at the crate pitch and in the orientation sketched.
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
gravelpitman, 2025-04-03:
@kaolpr  I was referring to these connectors on the DIPSU:
[Anytek 40A Power Connectors](https://www.anytek.com.cn/en/detail/326/9843.html)

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
(Blue backlit)

Upon rechecking, I confirmed they're actually rated for 40A – my earlier assessment was incorrect.

Assuming we abandon the concept involving Helper#1 and Helper#2 boards, I believe the LOP-400-12 power supply won't pose any size constraints. We'll have ample space for it, even in a 9HP enclosure.

We could design the PCB to accommodate both PSU options by adding additional mounting holes for Wurth standoffs (compatible with the LOP-300-12). These could be marked as DNP when using the LOP-400-12.

gravelpitman, 2025-04-11:
Summary of Key Arrangements for v2 Design:
**1.Simplified Architecture:**

-  Helper PCBs concept removed (eliminating the need for Molex 444321601 connectors).

- Fan control omitted from DIPSU (simplifying the design).

**2.Enclosure & Front Panel (FP):**
- Always use 9HP enclosure

- 9HP FP for 63HP crates.

- 10HP FP variant retained for standard 84HP crates.

**3.Mechanical Adjustments:**

- Replace Wurth standoffs under DIPSU Mezzanine: From: 9775066360 (H=6.6mm) → To: 9775046360R (H=4.6mm).

- Lower-profile P1 connector on DIPSU (possibly THT).

**4.Minor Corrections:**

- Realign mezzanine mounting holes with DIPSU.

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

- Resolve rocker switch interference with PCB.

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

**5.Potential Design Optimizations:**

- The implementation of custom, shorter bridges would enable:

- Relocation of the LOP-400 PSU to the PCB's rear section

- Enhanced 230VAC routing between the LOP-400 and DIPSU Mezzanine

**6.We are maintaining the use of LOP-400 power supplies.**

jordens, 2025-04-14:
With a mezzanine the main PCB can be used as an isolation barrier.

gkasprow, 2025-04-14:
Exactly. Original CPCIS PSUs use special handles with 100mil offset to enable bottom layer isolation and shielding.
DIPSU uses regular handles and rails, so we don't have enough space to isolate the THT terminals on the bottom side. We would have to trim them to nearly zero height.

gkasprow, 2025-04-14:
DIPSU prototype arrived

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

gkasprow, 2025-04-14:
the fan tray is on a way, expect it to get next week

jordens, 2025-04-14:
> DIPSU uses regular handles and rails, so we don't have enough space to isolate the THT terminals on the bottom side. We would have to trim them to nearly zero height.

But that's not true, right? For DISPU the offset is even larger than for the CPCIS style PSUs: 1 HP instead of 0.5 HP. You could easily add some isolation there. I assumed using the main PCB as isolation barrier makes it simpler.

gravelpitman, 2025-04-14:
Correct, @jordens  is right. DIPSU uses a custom panel with an additional HP on the left side, so space isn’t an issue.

gkasprow, 2025-04-14:
ok, I assumed standard 8 HP panel

gkasprow, 2025-04-14:
Why don't we use CPCIS handles for the DIPSU?

jordens, 2025-04-14:
I asked that above: https://github.com/sinara-hw/DIOT_PSU_integrated/issues/4#issuecomment-2757610161
Given the insertion and removal force it would likely be useful.

gravelpitman, 2025-04-14:
This requires a completely custom front panel with the ejector cutout relocated to the right side. At least, I haven't been able to find any off-the-shelf panels with an ejector in this configuration.

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

gkasprow, 2025-04-14:
you are going to machine the panel anyway, so what's the difference

gkasprow, 2025-04-14:
@gravelpitman can I get
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

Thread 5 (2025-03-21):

12V and 5V current monitoring ADC on I2C

jordens, 2025-03-21:
It would be useful to monitor the 12V shunt with an I2C ADC on M_SCL/M_SDA. The shunt circuitry is already there.
Same for the 5V standby rail. Maybe a known dual channel ADC like we have been using on Booster?

jordens, 2025-03-26:
E.g. sense the P12V0 and P5V voltages and currents (the existing `i_adc` signal and another shunt+ina for P5V) with a well-known ADS7924 on I2C_{SCL,SDA}. Any chance we can sneak this in still @Misio666 @kaolpr ?

Misio666, 2025-03-26:
I don't see a problem with it. But it will be necessary to modify the schematic and pcb design which will take an additional time.

Misio666, 2025-03-29:
I have made changes, please check the diagram. There are still a few things left that I plan to improve

Closed 2025-03-29.

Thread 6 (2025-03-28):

shunt filter

jordens, 2025-03-28:
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

Swap c11 and r40/r41, see ina194 datasheet. If you copied this error from somewhere else it would be good to also post it there.

gkasprow, 2025-03-28:
the original circuit is

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

Misio666, 2025-03-29:
Thanks, I fixed the diagram

Closed 2025-03-29.

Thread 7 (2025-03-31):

Inlet/fuse/switch/filter

jordens, 2025-03-31:
In the current designs' you won't be able to insert/replace the fuses.

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

The integrated modules take up less space but admittedly are expensive, e.g.
https://www.digikey.de/de/products/detail/schurter-inc/KMF1-1193-11/642330

gkasprow, 2025-03-31:
We were considering that, but they need manual cable crimping. Moreover, they don't look that good from the panel side.

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

jordens, 2025-03-31:
The one I linked clips in. No bezel, no screws.
Yes they do need short crimped jumpers, but maybe that's fine on balance, especially given the issue with the fuses (no external access and in the current design likely impossible to insert/replace).

gkasprow, 2025-04-01:
We will move the converter by a few mm and make space  for fuses

jordens, 2025-04-14:
I can imagine that the cable actually helps with assembly. If the connector and switch are soldered to the PCB, you can't add or remove the panel anymore or you need to open up the panel so much that you can't use the sealing/bezel/brim of the switch/connector.

And since you already need crimping for the LOP cable, why not just add one more. Take the same type (cable shoe to JST) if you want.

That would then also trivially open up the solution to skipping the entire mezzanine (5V PSU and relay) for the classic EEM variant (https://github.com/sinara-hw/EEM_PWR_MOD_AC/issues/17) and connecting the Meanwell directly to the power entry module without a mezzanine.

gravelpitman, 2025-04-17:
I'm fine with it. Mechanically, it's better for me than the mezzanine.
Inserting a new fuse is now difficult but not impossible – it still requires removing the enclosure, etc.
In my opinion, crimping the connectors isn't an issue.
But since we're almost done with the V2 version of the PCB, I'd suggest pushing this change to the next board revision (V3).

gkasprow, 2025-04-17:
I just removed and inserted the fuses; It's easy with tweezers

gkasprow, 2025-04-17:
When the fuses are blown, severe damage to the converter module is usually experienced.
The fuse is for safety; it's not foreseen that the user will replace it.

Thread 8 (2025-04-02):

Remove fan controls and helper connector

kaolpr, 2025-04-02:
**Context**

We had a discussion with @gkasprow, and we've decided to:

- introduce a modification to DIOT backplane (see https://github.com/sinara-hw/DIOT_Backplane/issues/5) that will give us easy access to monitoring I2C,
- move all fan controls to fan unit (in development) to be controlled with I2C.

This will simplify DIPSU design and make additional connector redundant.

**Definition of done**

- [x] Remove all fan controls
- [x] Remove helper board connector

martafafara, 2025-04-14:
Introduced in new project (actually in progress)

jordens, 2025-04-14:
https://github.com/sinara-hw/DIOT_Backplane_Mezzanine

Closed 2025-04-14.

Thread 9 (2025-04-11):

PE terminal

jordens, 2025-04-11:
As in https://github.com/sinara-hw/EEM_PWR_MOD_AC/issues/16 there should be a terminal to connect PE to crate.
The full DIOT crate has the terminal on the power backplane.

Currently DIPSU PE goes to the front panel via the angle brackets and to the enclosure. My guess is that that connection alone isn't sufficient to meet requirements of PE robustness/continuity.

We don't have PE on the FCI connector which makes putting it onto the backplane and the mezzanine a bit difficult. Easiest would be to put it onto the main PCB of DIPSU.

martafafara, 2025-04-16:
I'm currently working on the next revision and I would like to follow your suggestion about the PE connection. There will be 2 different ways. The first one is a bush connector as on the Power Backlpane ([EDA-04212](https://edms.cern.ch/item/EDA-04212-V4-0/0)) . It allows to use DIPSU without the case and keeping its all functionality. The second solution is the terminal builed into the DIPSU case, but this approach could be wider explained by @gravelpitman. The second has such advantage that it ensures more connection points.

jordens, 2025-04-17:
I suspect that relying on washers to make reliable contact through powder coat is a no-go for the MOP requirements, maybe even relying on contact via the nut and thread.

gravelpitman, 2025-04-17:
Ok, I will add coating-free zone

Closed 2025-04-17.

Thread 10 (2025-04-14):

Conclusions after prototype assembly

Misio666, 2025-04-14:
DIOD_PSU_Mezzanine
- [ ] Change the holes size in DIOT_PSU_Mezzanine set to 3.2mm and pads to 5.6mm,
- [ ] Make support board (or tool) for SW1 (DF62J12S2AHQA), increas mounting high to ~1.6mm,
- [ ] In the IEC-60320 connector (SCHURTER_GSF1.2202.31) PE pin conectro need to bend the PE up by 90deg,
- [ ] add two ceramic fuse 250VAC/6.3A for the IEC-60320 connector.

DIOD_PSU_integrated
- [ ] Enlarge the holes for the J2 (MOLEX_44432160), the holes on the board have a tight fit,
- [ ] Turn all angular LED by 180deg,
- [ ] Change LD1 an LD11 to GREEN, rest shoud by RED,
- [ ] Change bar graph LED to RED,
- [ ] Label all LED on BOT PCB side,
- [ ] Moving D1 close to the backplane connector,
- [ ] Change P1 from SMD to THT, easier positioning,
- [ ] Shrink pads for J7 and J11, too loose fit,
- [ ] No star shim for PSU screw,
- [ ] Add test pads to: I2C, +5, +12V and GND net,
- [ ] After switching off power supply, bargraph diodes blink once, add PMOS at LED power bar controled by PG signal

gkasprow, 2025-04-14:
change 100% bar graph LED to red, rest should be green.
RED = alert, Green = OK

martafafara, 2025-04-15:
Have you tested boards with mounted front panel? It would support mezzaine parts and no further mechanical changes will be required

gravelpitman, 2025-04-15:
- "Make support board (or tool) for SW1 (DF62J12S2AHQA), increas mounting high to ~1.6mm" Why do you want to do this? Isn't it because there's interference between SW1 and the front edge of the mezzanine?

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

- "Enlarge the holes for the J2 (MOLEX_44432160), the holes on the board have a tight fit," After the concept change (added DIOT Backplane Mezzanine), this connector is no longer needed, so we don't have to do it.

- @Misio666  What are your thoughts on the bridges? Didn't the MeanWell PSU bend after it was screwed in?

martafafara, 2025-04-17:
Pads for J7 and J11 are designed according to manufacturer recommendation. No changes is planned.

gkasprow, 2025-04-17:
The molex PSU doesn't bend

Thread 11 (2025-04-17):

WP-SMRA cost optimization

kaolpr, 2025-04-17:
Following remark from @gkasprow I suggest replacing 7466313R with 74663125R (M2.5) or 7466312R (M2). These replacements cut the cost in half.

gkasprow, 2025-04-17:
I don't know if those are a good solution. They will likely delaminate with pads when DIPSU experiences a strong mechanical shock.
I'd use low cost THT alternatives:
https://www.tme.eu/pl/details/73-3299-21_0030/koncowki-lutownicze-pcb/osterrath/
https://www.tme.eu/pl/details/73-3299-25_0016/koncowki-lutownicze-pcb/osterrath/
https://www.tme.eu/pl/details/keys7695/koncowki-lutownicze-pcb/keystone/7695/

gravelpitman, 2025-04-18:
OK, I see your point. Cost and the whole load going through the top layer of copper are good points.
I don't like any of your proposals. The M4 thread forces us to use M4 screws (obviously), which have taller heads and reduce the clearance between the enclosure and the guide rails.

This one (https://www.tme.eu/pl/details/keys7695/koncowki-lutownicze-pcb/keystone/7695/) is far too big (11.5 mm long).

Additionally, I'm concerned about positioning these elements during soldering. If the holes are too loose, the part might shift too much, and bolting it to the enclosure could flex something and introduce stress to the PCB.

I would suggest using a cube like this one (https://www.newark.com/ettinger/005-60-223/standoff-cube-brass-9mm/dp/59M4071). That way, we could bolt it to the enclosure first and then mount the PCB on it. If we make ø2.9 mm holes in the PCB, we’ll have sufficient clearance and avoid introducing any mechanical stress to the board, while still ensuring secure mounting.
Oh, and it's cheap too.

gkasprow, 2025-04-18:
Those are quick examples Agnieszka proposed; use any THT that works for you.

gravelpitman, 2025-04-18:
I couldn't find anything that would fit better — your suggestions were the closest.
We'll stick with the Ettinger 005.60.223. I'm closing this issue.

Closed 2025-04-18.

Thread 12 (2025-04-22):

RELAY logics is inverted

gkasprow, 2025-04-22:
The main relay is wired like the one on the CERN boards to reboot the crate using an external BNC.
In our case, it must be connected with the off state by default.

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

martafafara, 2025-04-23:
When looking into the big picture it seems to be correct. Take note to the control part. The signal PS_ON_N may be assumed as "0" by default, then reverted to PS_ON and relay is activated cutting off power output. The main system controller have to change state to power up the whole system. The standby P5V0 should be used.

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

Please, correct if I understood it wrong or the controlling assumptions where predicted in another way.

gkasprow, 2025-04-23:
Yes. But that would work if contacts were not swapped

śr., 23 kwi 2025, 07:40 użytkownik martafafara ***@***.***>
napisał:

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

martafafara, 2025-04-23:
Done

Closed 2025-04-23.

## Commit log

2025-02-20 Project reorganization, add daughter board
    [DIOT_PSU_integrated.PrjPcb, DIOT_PSU_integrated.SchDoc]
2025-02-20 Rebuild file structure , add mezzanine board
    [DIOT_PSU_Mezzanine.SchDoc, DIOT_PSU_doutherBoard.step, DIOT_PSU_integrated - Main.PrjPcb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]
2025-02-21 Secen mezzanine board concept
    [DIOT_PSU_Mezzanine.SchDoc, DIOT_PSU_doutherBoard.step, DIOT_PSU_integrated - Main.PrjPcb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]
2025-02-21 Del unuse files
    [controller.schdoc, power_stage.schdoc, ratopus.PcbDoc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]
2025-02-23 New wersion of mezzazine board and mechanical
    [DIOT_PSU_Mezzanine.SchDoc, DIOT_PSU_doutherBoard.PcbDoc, DIOT_PSU_doutherBoard.step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]
2025-02-23 Add rail keepout
2025-02-24 Daughter board update and PCB layout
    [DIOT_PSU_Mezzanine.SchDoc, DIOT_PSU_doutherBoard.PcbDoc, DIOT_PSU_doutherBoard.step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]
2025-02-25 Befor remove LTC4412HVIS6#PBF
    [DIOT_PSU_Mezzanine.SchDoc, DIOT_PSU_doutherBoard.PcbDoc, DIOT_PSU_doutherBoard.step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]
2025-02-25 100% connection layout
    [DIOT_PSU_Mezzanine.SchDoc, DIOT_PSU_doutherBoard.PcbDoc, DIOT_PSU_doutherBoard.step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]
2025-02-26 Minor schematic and layout update
    [DIOT_PSU_integrated.SchDoc, I_Sense.SchDoc, LED_Bargraph.SchDoc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]
2025-02-27 New layout concept
    [DIOT_PSU_Mezzanine.SchDoc, DIOT_PSU_doutherBoard.PcbDoc, DIOT_PSU_doutherBoard.step]
2025-03-10 change file name
    [DIOT_PSU_doutherBoard.PcbDoc]
2025-03-10 push intermediate mechanical design
    [DIOT_PSU_Mezzanine.PcbDoc, DIOT_PSU_Mezzanine.SchDoc, DIOT_PSU_doutherBoard.step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]
2025-03-11 molex EEM +12V connectors
    [DIOT_PSU_Mezzanine.PcbDoc, DIOT_PSU_Mezzanine.SchDoc, DIOT_PSU_doutherBoard.step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]
2025-03-12 first release candidate
    [DIOT_PSU_Mezzanine.PcbDoc, DIOT_PSU_Mezzanine.SchDoc, DIOT_PSU_integrated.SchDoc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]
2025-03-15 Made changes from issiue - Primary project review
    [DIOT_PSU_Mezzanine.PcbDoc, DIOT_PSU_integrated - Main.PrjPcb, DIOT_PSU_integrated.SchDoc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]
2025-03-16 Intermediate mechanical change
    [DIOT_PSU_Mezzanine.PcbDoc, DIOT_PSU_integrated - Main.PrjPcb, DIOT_PSU_integrated.SchDoc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]
2025-03-24 Components placement update
    [DIOTPSU-A01.v1.stp, DIOTPSU-A02.iam.v1.1.stp, DIOTPSU-A02.v1.stp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]
2025-03-26 100% connections
    [DIOT_PSU_integrated.SchDoc, EEPROM.SchDoc]
2025-03-29 Add ADS7924 and P5V0 current measuring
    [ADC.SchDoc, DIOT_PSU_Mezzanine.SchDoc, DIOT_PSU_integrated - Main.PrjPcb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]
2025-03-29 Add ADS7924 and P5V0 current measuring , change ADC AVDD to P3V3
    [IAMP.SchDoc, LED_Bargraph.SchDoc]
2025-03-30 Layout opdate
    [ADC.SchDoc, DIOT_PSU_integrated - Main.PrjPcb, DIOT_PSU_integrated.SchDoc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]
2025-03-30 Mazazzine update
    [DIOT_PSU_Mezzanine.PcbDoc]
2025-03-30 Update Mezzanine bord layput and L/N pad
    [DIOT_PSU_Mezzanine.PcbDoc]
2025-03-31 Almost final release
    [DIOT_PSU_integrated - Main.PrjPcb, DIOT_PSU_integrated - Mezzanine.PrjPcb, FAN_Control.SchDoc]
2025-04-02 Release version
    [ADC.SchDoc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]
2025-04-02 Release version - PSU binding post move -2mm
    [DIOT_PSU_Mezzanine.GBL, DIOT_PSU_Mezzanine.GBO, DIOT_PSU_Mezzanine.GBP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]
2025-04-17 V2 to review. Removed fan control. Introduced improvements in issues. Post testing remarks included. PE terminal added.
    [ADC.SchDoc, DIOT_PSU_Mezzanine.PcbDoc, DIOT_PSU_Mezzanine.SchDoc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]
2025-04-22 Implemented BOM simplifications, included missing 3D body, new PE connection, remodeled case mounting.
    [ADC.SchDoc, DIOT_PSU_Mezzanine.PcbDoc, DIOT_PSU_integrated - Main.PrjPcb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]
2025-04-23 Corrected front panel
    [DIOT_PSU_integrated - Main.PrjPcb]
2025-04-23 Changed relay outputs according to issue #12
    [DIOT_PSU_Mezzanine.PcbDoc, DIOT_PSU_Mezzanine.SchDoc, DIOT_PSU_integrated - Main.PrjPcb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]
